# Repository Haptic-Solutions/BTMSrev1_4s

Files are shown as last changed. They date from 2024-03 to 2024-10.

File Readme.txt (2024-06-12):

Open Source Universal Battery Controller
Test battery is 4S Lithium Ion Pack
16.8V 2.6Ah rated. 38.48Wh Nominal
Please note that this device is a prototype and all features are still being extensively tested, some features aren't fully implement, and others are awaiting further polishing. Please excuse our mess as we continue to develop this system, it's documentation, and source/design repository.
Watch your step! The workshop is messy. ;)

	Though, this pack is worn out a bit as these are recycled cells. No worries though, as this BMS, Charger, and Power Management System will measure, and account for performance variations between batteries and chemistry types. Features include, but are not limited to:

    • BUCK-BOOST charge input to accommodate a wide range of battery configurations and supports charge voltage inputs from 5v-25v
    • USB-PD and USB2.0 charge to support a wide range of USB chargers up to 100watt.
    • AUX CHARGE PORT for solar applications
    • 2S, 3S, OR 4S support via jumper on the cell inputs
    • POWER SWITCH MODES ranging from push-and-hold, to automatic power on when charger power disconnected
    • FULL ACCESS to a wide range of settings such as cell max voltage and current
    • REDUNDANT SAFETY SYSTEMS not just in firmware but in hardware via over-voltage detection, shutdown, and disabling once any cell reaches 4.3v
    • ERROR REPORTING and TELEMETRY in a simple to access single letter command set via built-in USB serial or AUX UART header accessed by a terminal emulator
    • LCD SUPPORT via UART output that is configurable
    • HEATER CONTROL for cold environments with board and battery temperature sensors

Specs:
    • 25V 5A max charge input
    • 18V 10A max battery output, 2s-4s configurations, max 4.3v/cell
    • Dual UART with one dedicated to USB FTDI
    • dsPIC30F4011 micro-controller ~14mips
    • C codebase
    • 0.015mA deep-sleep (diode leakage, we aim to improve this)

Stay tuned for developments. We've got a lot of ground to cover before we release this into the wild! Our goal is to help other hobbyists be safer with batteries while getting their max performance in a very wide range of supported applications and cell chemistry types!
Copyright (2024) Haptic Solutions Inc.

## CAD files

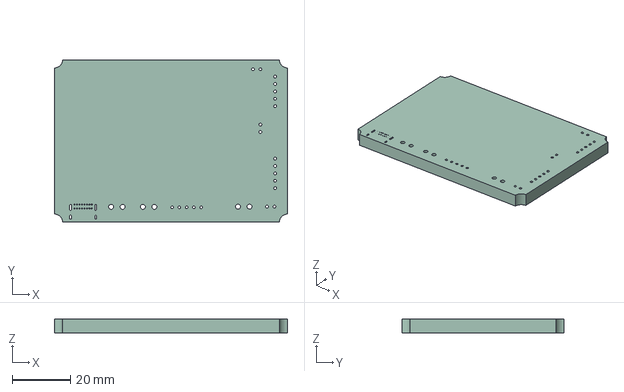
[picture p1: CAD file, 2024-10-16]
KICAD/BTMS.step
80.1 x 55.8 x 4.69 mm

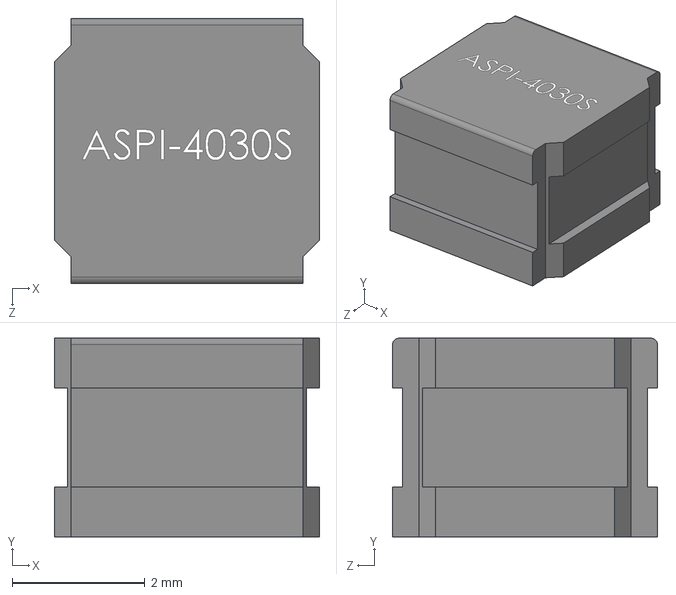
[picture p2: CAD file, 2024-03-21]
KICAD/inductorModel/ASPI-4030S-4R7M-T.step
4.00 x 3.00 x 4.00 mm

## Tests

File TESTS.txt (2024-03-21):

####################################
###  Functionality and safety tests to be performed. ###
####################################

******************************************************************************************************************************
## Functionality::

User interface:

Charging input(s) modes (USB, battery-to-battery, 5v-20v power supply, solar in with varying sunlight conditions):

Voltage output and power switch modes:

Charging efficiency > 85% through all modes:

Heater system:

******************************************************************************************************************************
## Safety systems::

Charge input over current detection and shutdown:

Power output over current detection and shutdown:

Cell low voltage shutdown and reporting:

Cell high voltage shutdown and reporting:

Over temperature shutdown for board and battery:

Under temperature charge slowdown/prevention:

******************************************************************************************************************************
## Compliance tests::

RF emissions within limits:

Battery Safety:

******************************************************************************************************************************
## Destructive tests::

Short circuit instant shutdown without blowing fuses:

Circuit board max current testing. Use blank boards and high-current source:

Overheat shutdown testing and abuse:

Battery HV disconnect fuse triggering at 4.3v per cell:

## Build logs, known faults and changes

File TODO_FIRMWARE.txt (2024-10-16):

####################################
##  Firmware features and bugs to be fixed and added ##
####################################

Fix: Charging routine not fully charging the battery and then maintaining the voltage. Testing fix.

Implement: MPPT for solar charging.

Implement: I2C communication to USB3.1 PD chip. Mostly done. Bug where re-plugging in the charger does not initiate USB3 charging. Testing fix for this. Seems to work alright after changing some things. Keep an eye on this.

Implement: Power button features. Done. Need to add a few features to this. Maybe an err ACK top bring back charge meter after a non-fatal error?

Implement: Better CLI interface such as more info available at request, and easier to understand variable names. Partly Done. Need to implement HUD config system.

Implement: Be able to change ALL settings from CLI. Mostly Done.

Fix: Fault light doesn't always turn on when an error is logged, especially when system shuts down, and doesn't always blink as it should.

Implement: New I2C hardware such as analog input and 4 bit digital IO expander need handlers.

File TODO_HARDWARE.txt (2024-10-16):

####################################
##  Hardware features and bugs to be fixed and added ##
####################################

Add: Small electrolytic decoupling capacitors to output of buck-boost converter. Might need some on input as well. Seems to trip USB-PD charges when average current isn't anywhere near it's set limit. Done some. Need to test more.

Upgrade: Current output rating is only 10 amps. Try to get it up to 15 amps. Not high priority. May not even bother with this version as it's small board size limits the current.

Fix: Lots of EMI coming from multiplexed LED drive circuit. <- Moved resistors as close to dsPIC as possible. Added resistor to multiplex selector. It's a little better. This might not be as bad as it seems.

Fix: USB and AUX charge inputs will output power to one or the other. This is NOT safe for either device that may be plugged in. <- New design uses a MOSFET network to switch USB input on/off. Need to test when new boards come in.

Fix: Capacitive loads cause inrush current that trips the over current protection circuit. A pre-charge circuit with resistors might work with some types of loads, but probably not when loads are both resistive and capacitive. <- Changed power source of
current sense IC's to an IO pin of the micro controller so that they can be reset when a known inrush current is about to be switched on. This did not work. Reverted back to powering current sense IC's from 3.3V analog supply.
Added RC network to turn MOSFETS on much slower. Need to test.

Fix: USB-PD chip senses wrong current with current schematic. Removed diode causing problems. Need better solution for powering PD chip from USB-C or Aux as it is also our 3.3V regulator to power the FTDI chip. Use separate regulator?

Fix: Sleep mode power draw still not low enough. Seems using these 40V Schottky diodes is part of the problem. Test show that removing D6 on REV1A(P) reduces sleep current draw from 0.15mA to just 0.05mA. Still not low enough, but better.
I only used these diodes because of their small size for how much current they can pass. Need to investigate further. Found that the buck-boost output diode is another source of leakage current. Removing the path from this circuit to the battery drops
the leakage current from battery down to 0.002mA which is within error of my cheap multi-meter. A 100mAh battery would last 5.7 years at this current while in sleep mode, and a 2.6Ah pack like the one I've been using to test would last 
~148 years in sleep mode.
Using newer design should improve this as the battery is completely disconnected when in deep-sleep mode.

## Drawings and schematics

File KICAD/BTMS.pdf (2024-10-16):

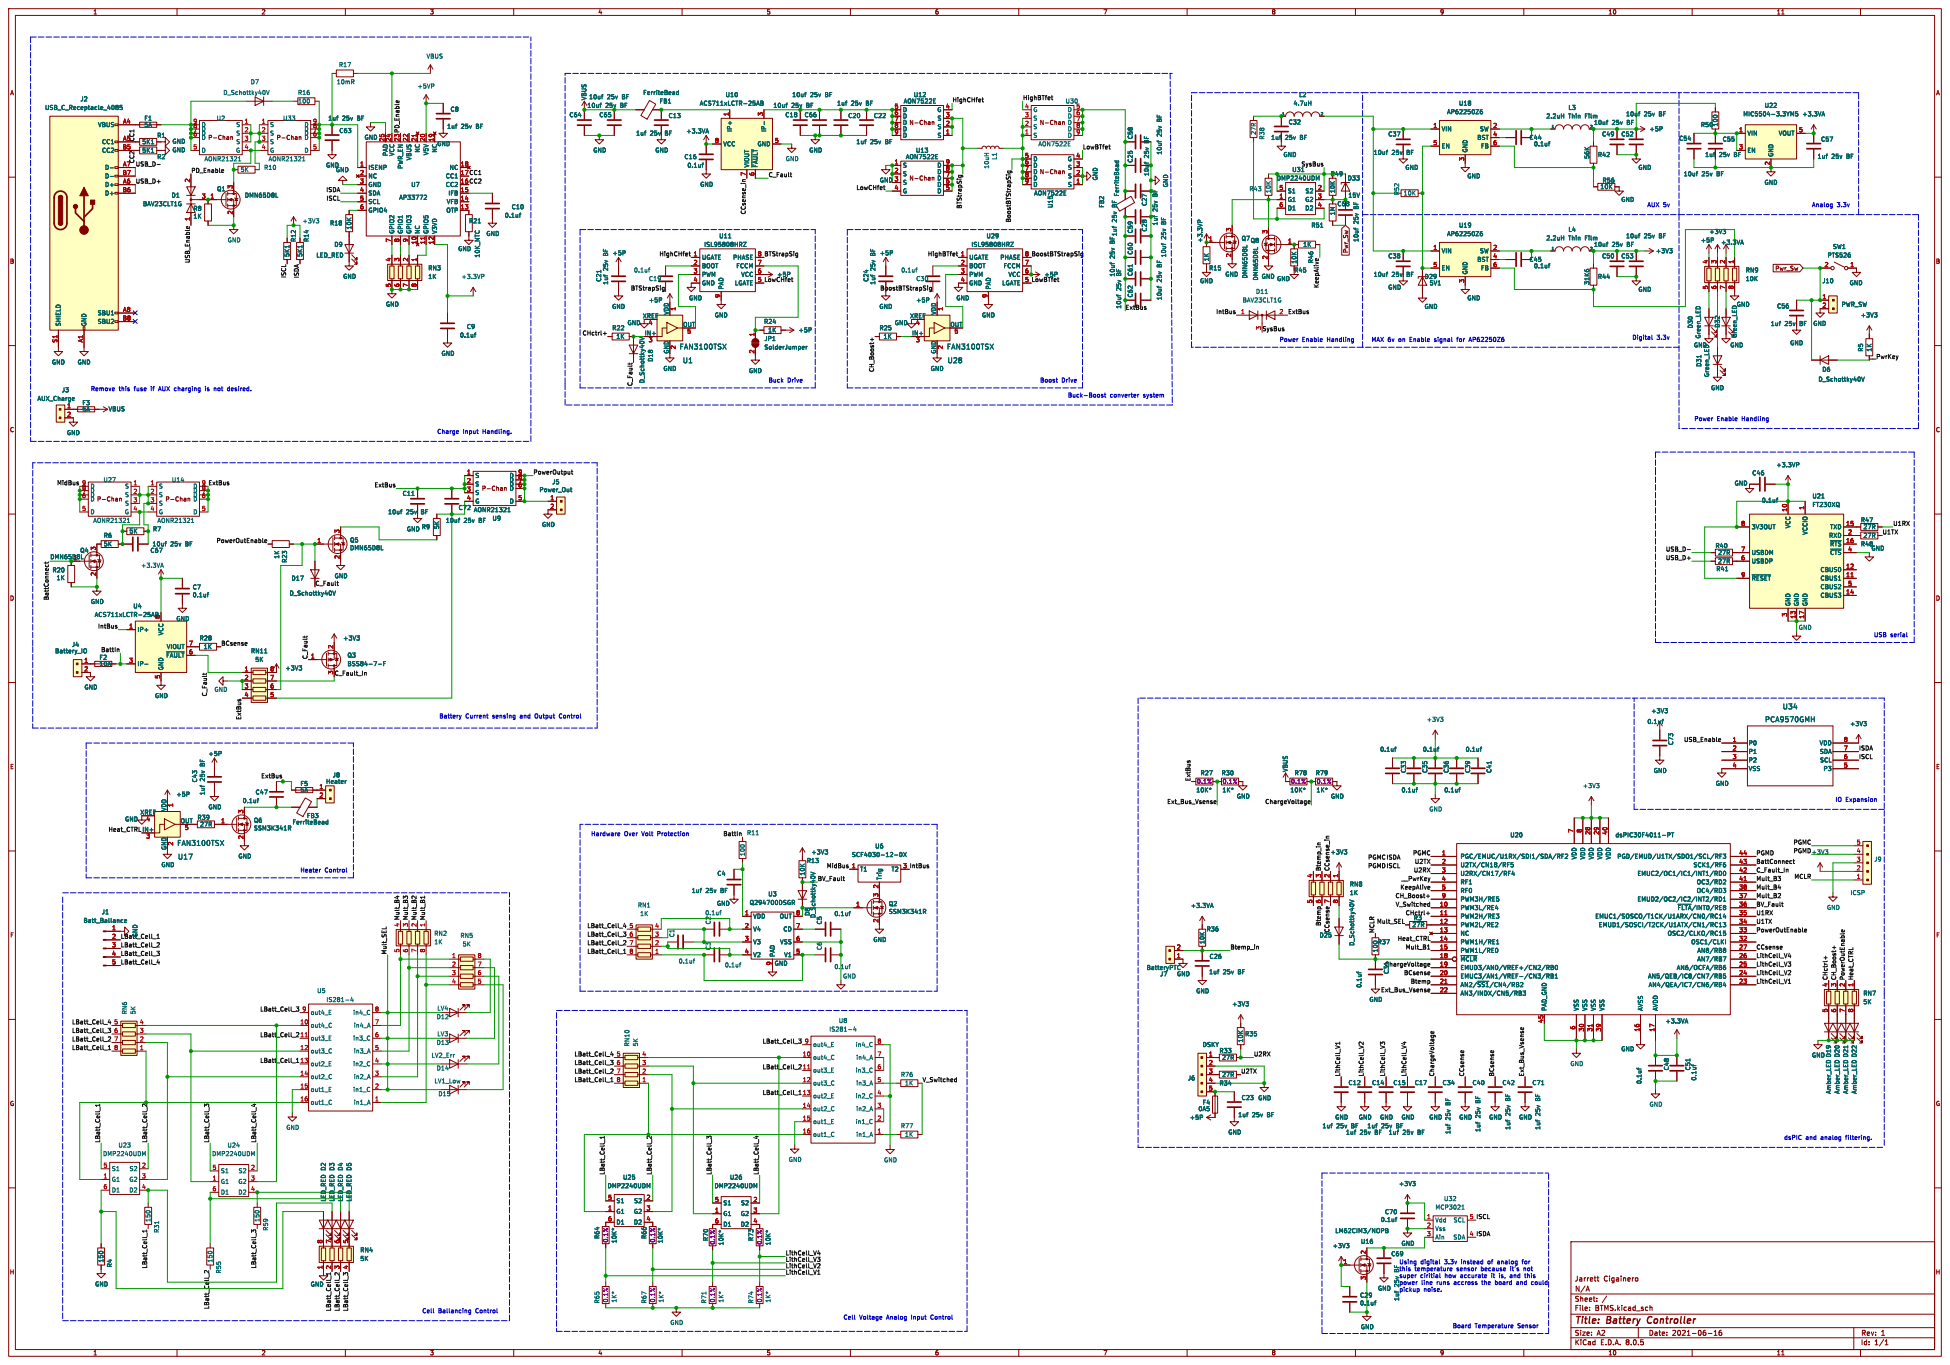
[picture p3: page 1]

7 VCC 8 U10 ACS711xLCTR-25AB UGATE 1 BOOT 2 PWM 3 GND 4

1 IP- 3 GND 5 ~{FAULT} 6 VIOUT

Power Enable Handling Boost Drive Charge Input Handling. R8

ISL95808HRZ UGATE 1 BOOT 2 PWM 3 GND 4

LGATE 5 VCC 6 FCCM 7 PHASE 8 PAD

MAX 6v on Enable signal for AP62250Z6

USB serial IO Expansion

Hardware Over Volt Protection Battery Current sensing and Output Control

Cell Voltage Analog Input Control

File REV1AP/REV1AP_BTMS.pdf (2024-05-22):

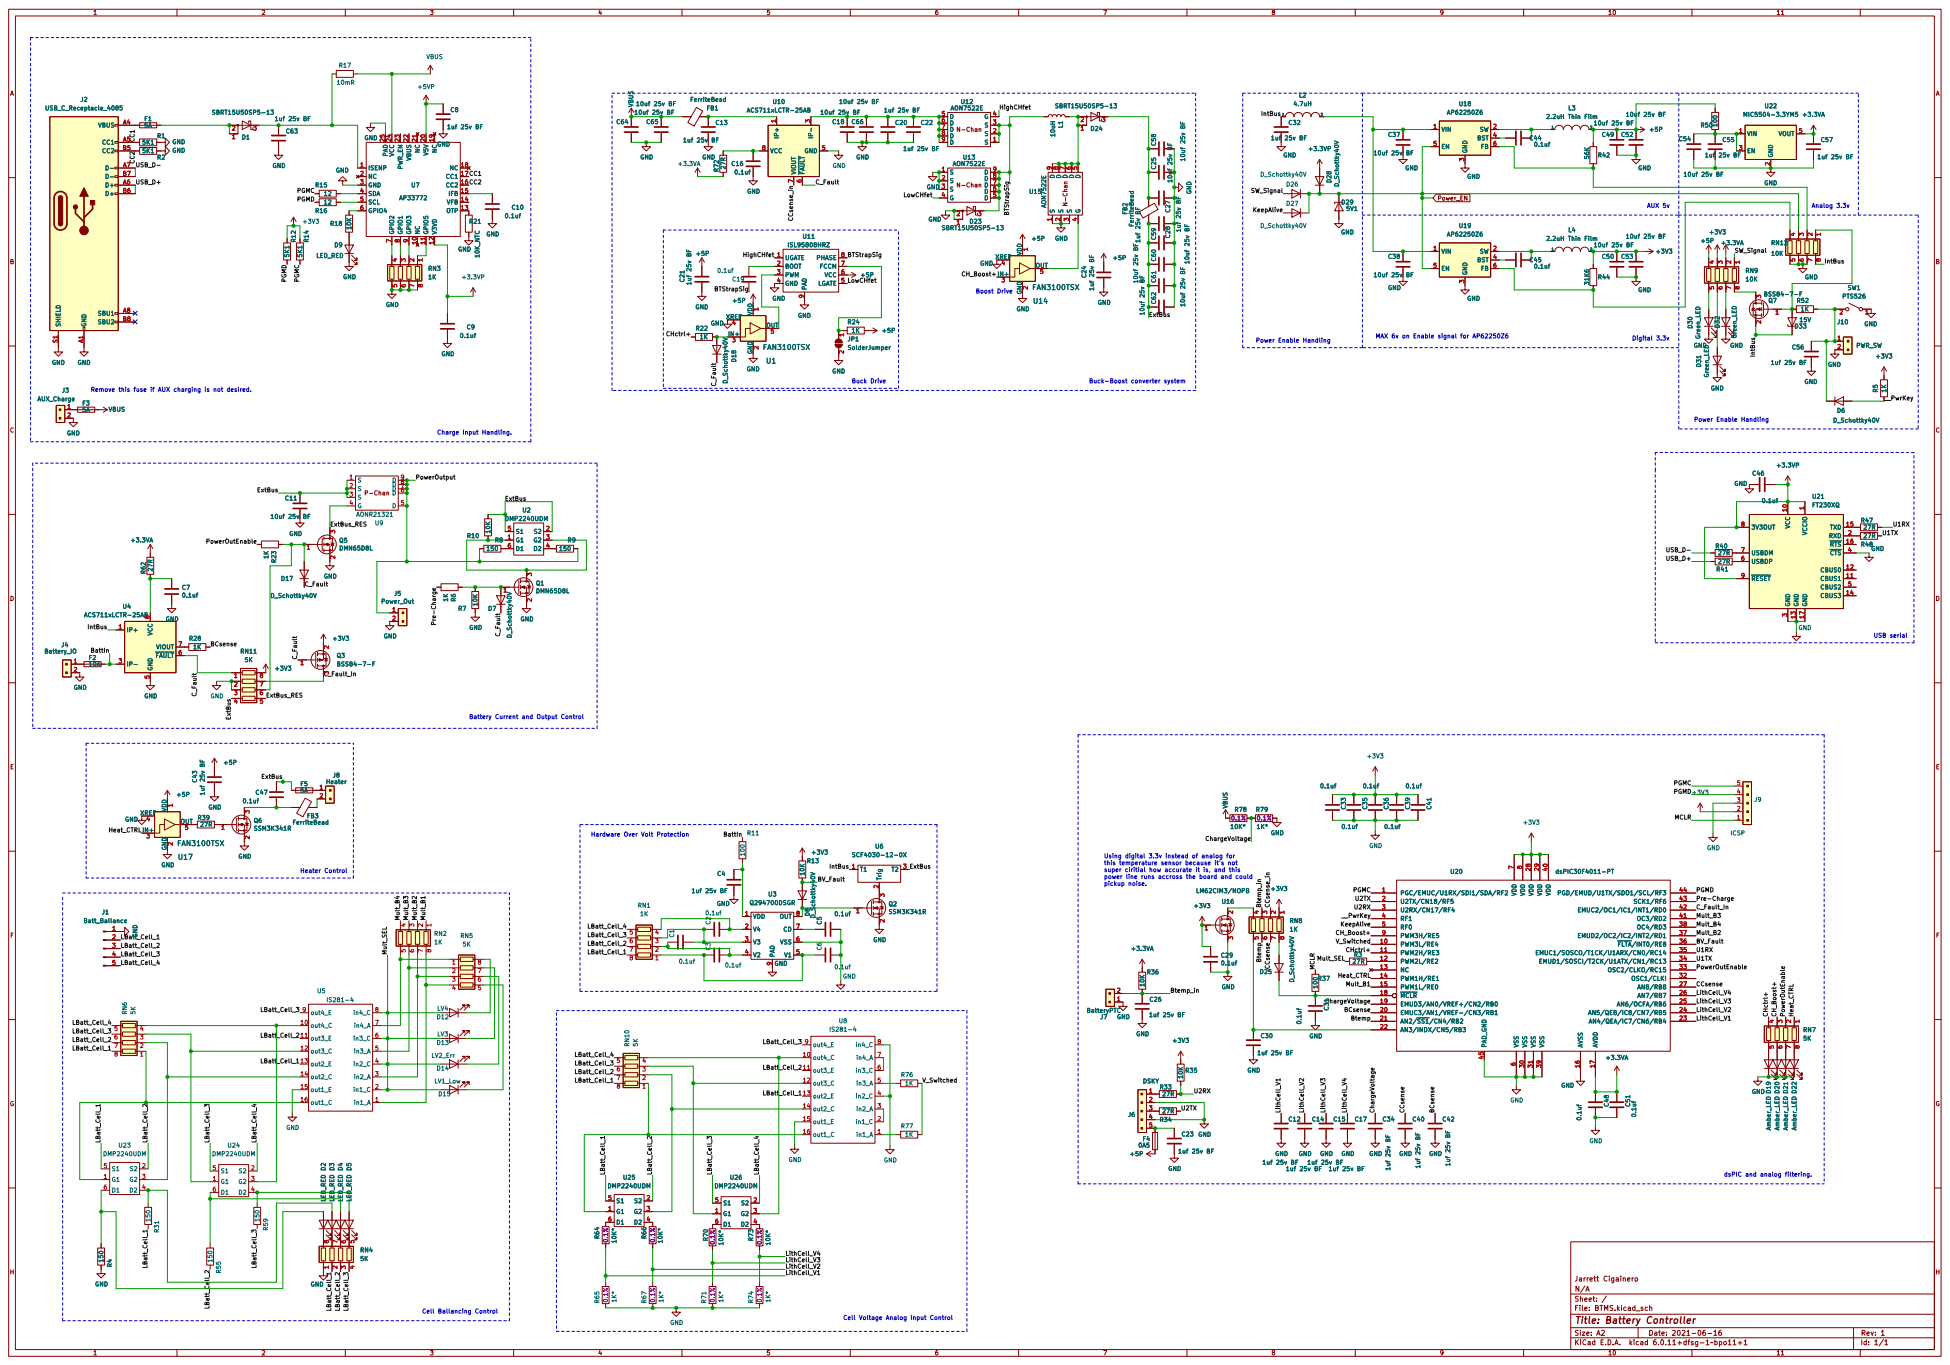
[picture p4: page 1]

1 IP- 3 GND 5 ~{FAULT} 6 VIOUT

9 +5P C24 1uf 25v BF L1 10uH GND C60 10uf 25v BF C62 10uf 25v BF GND FB2 FerriteBead C28 1uf 25v BF GND

Battery Current and Output Control

Hardware Over Volt Protection

dsPIC and analog filtering.

Jarrett Cigainero
Id: 1/1 Title: Battery Controller File: BTMS.kicad_sch Sheet: / N/A

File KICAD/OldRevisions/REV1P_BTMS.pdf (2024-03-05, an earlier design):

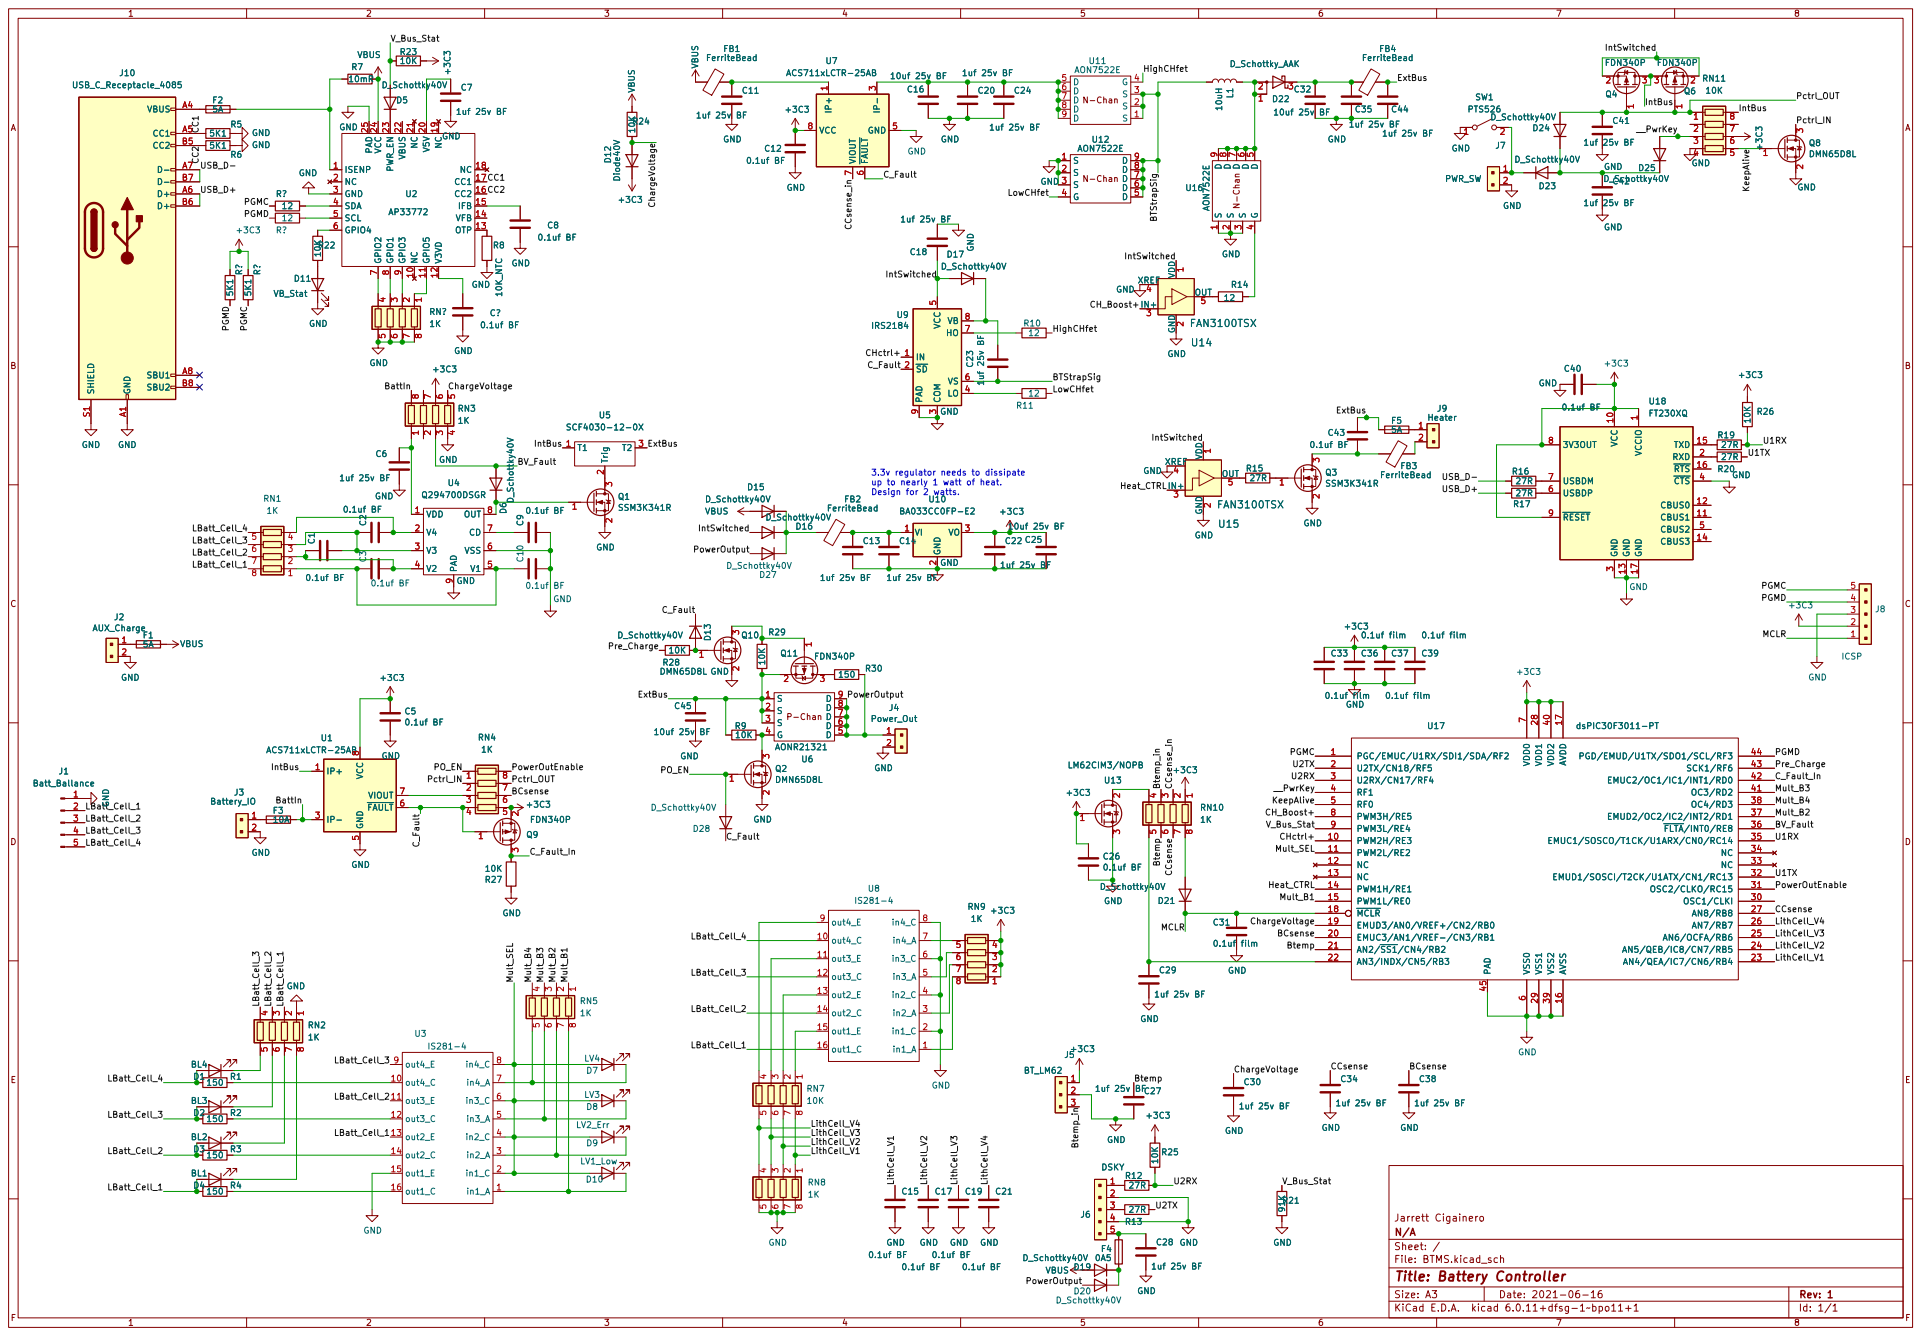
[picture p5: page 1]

1 IP- 3 GND 5 ~{FAULT} 6 VIOUT

Jarrett Cigainero
Id: 1/1 Title: Battery Controller File: BTMS.kicad_sch Sheet: / N/A

VBUS D20 D_Schottky40V GND GND GND

0.1uf BF GND GND GND

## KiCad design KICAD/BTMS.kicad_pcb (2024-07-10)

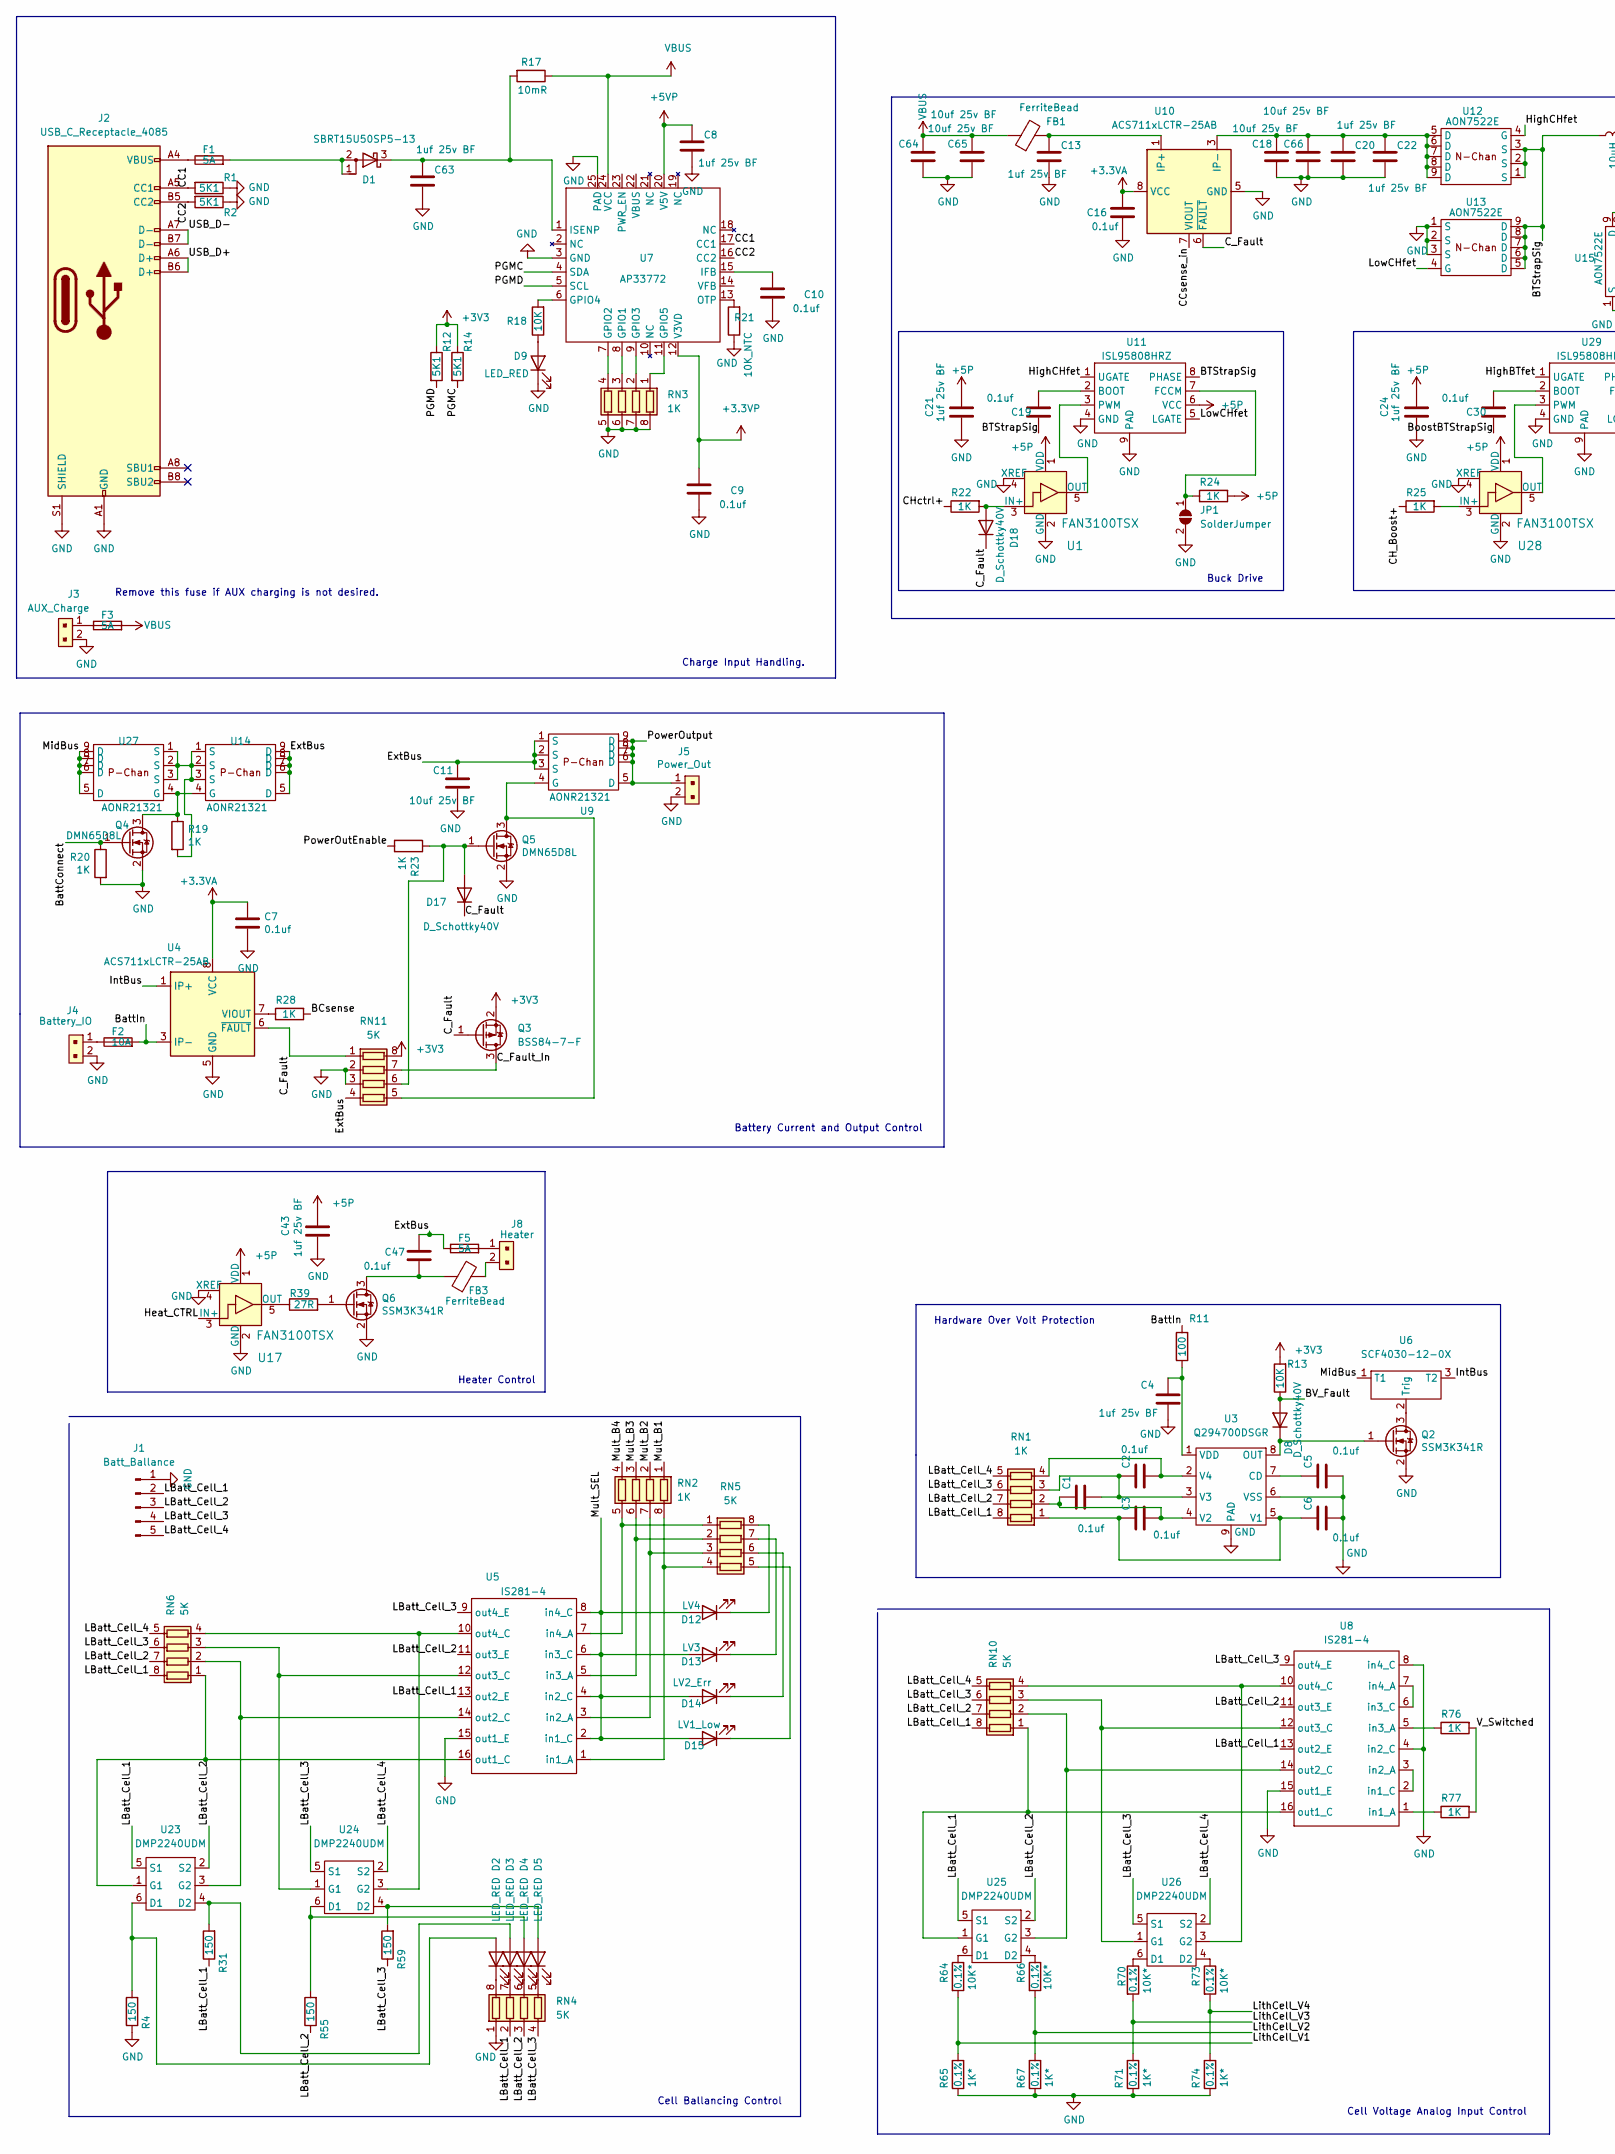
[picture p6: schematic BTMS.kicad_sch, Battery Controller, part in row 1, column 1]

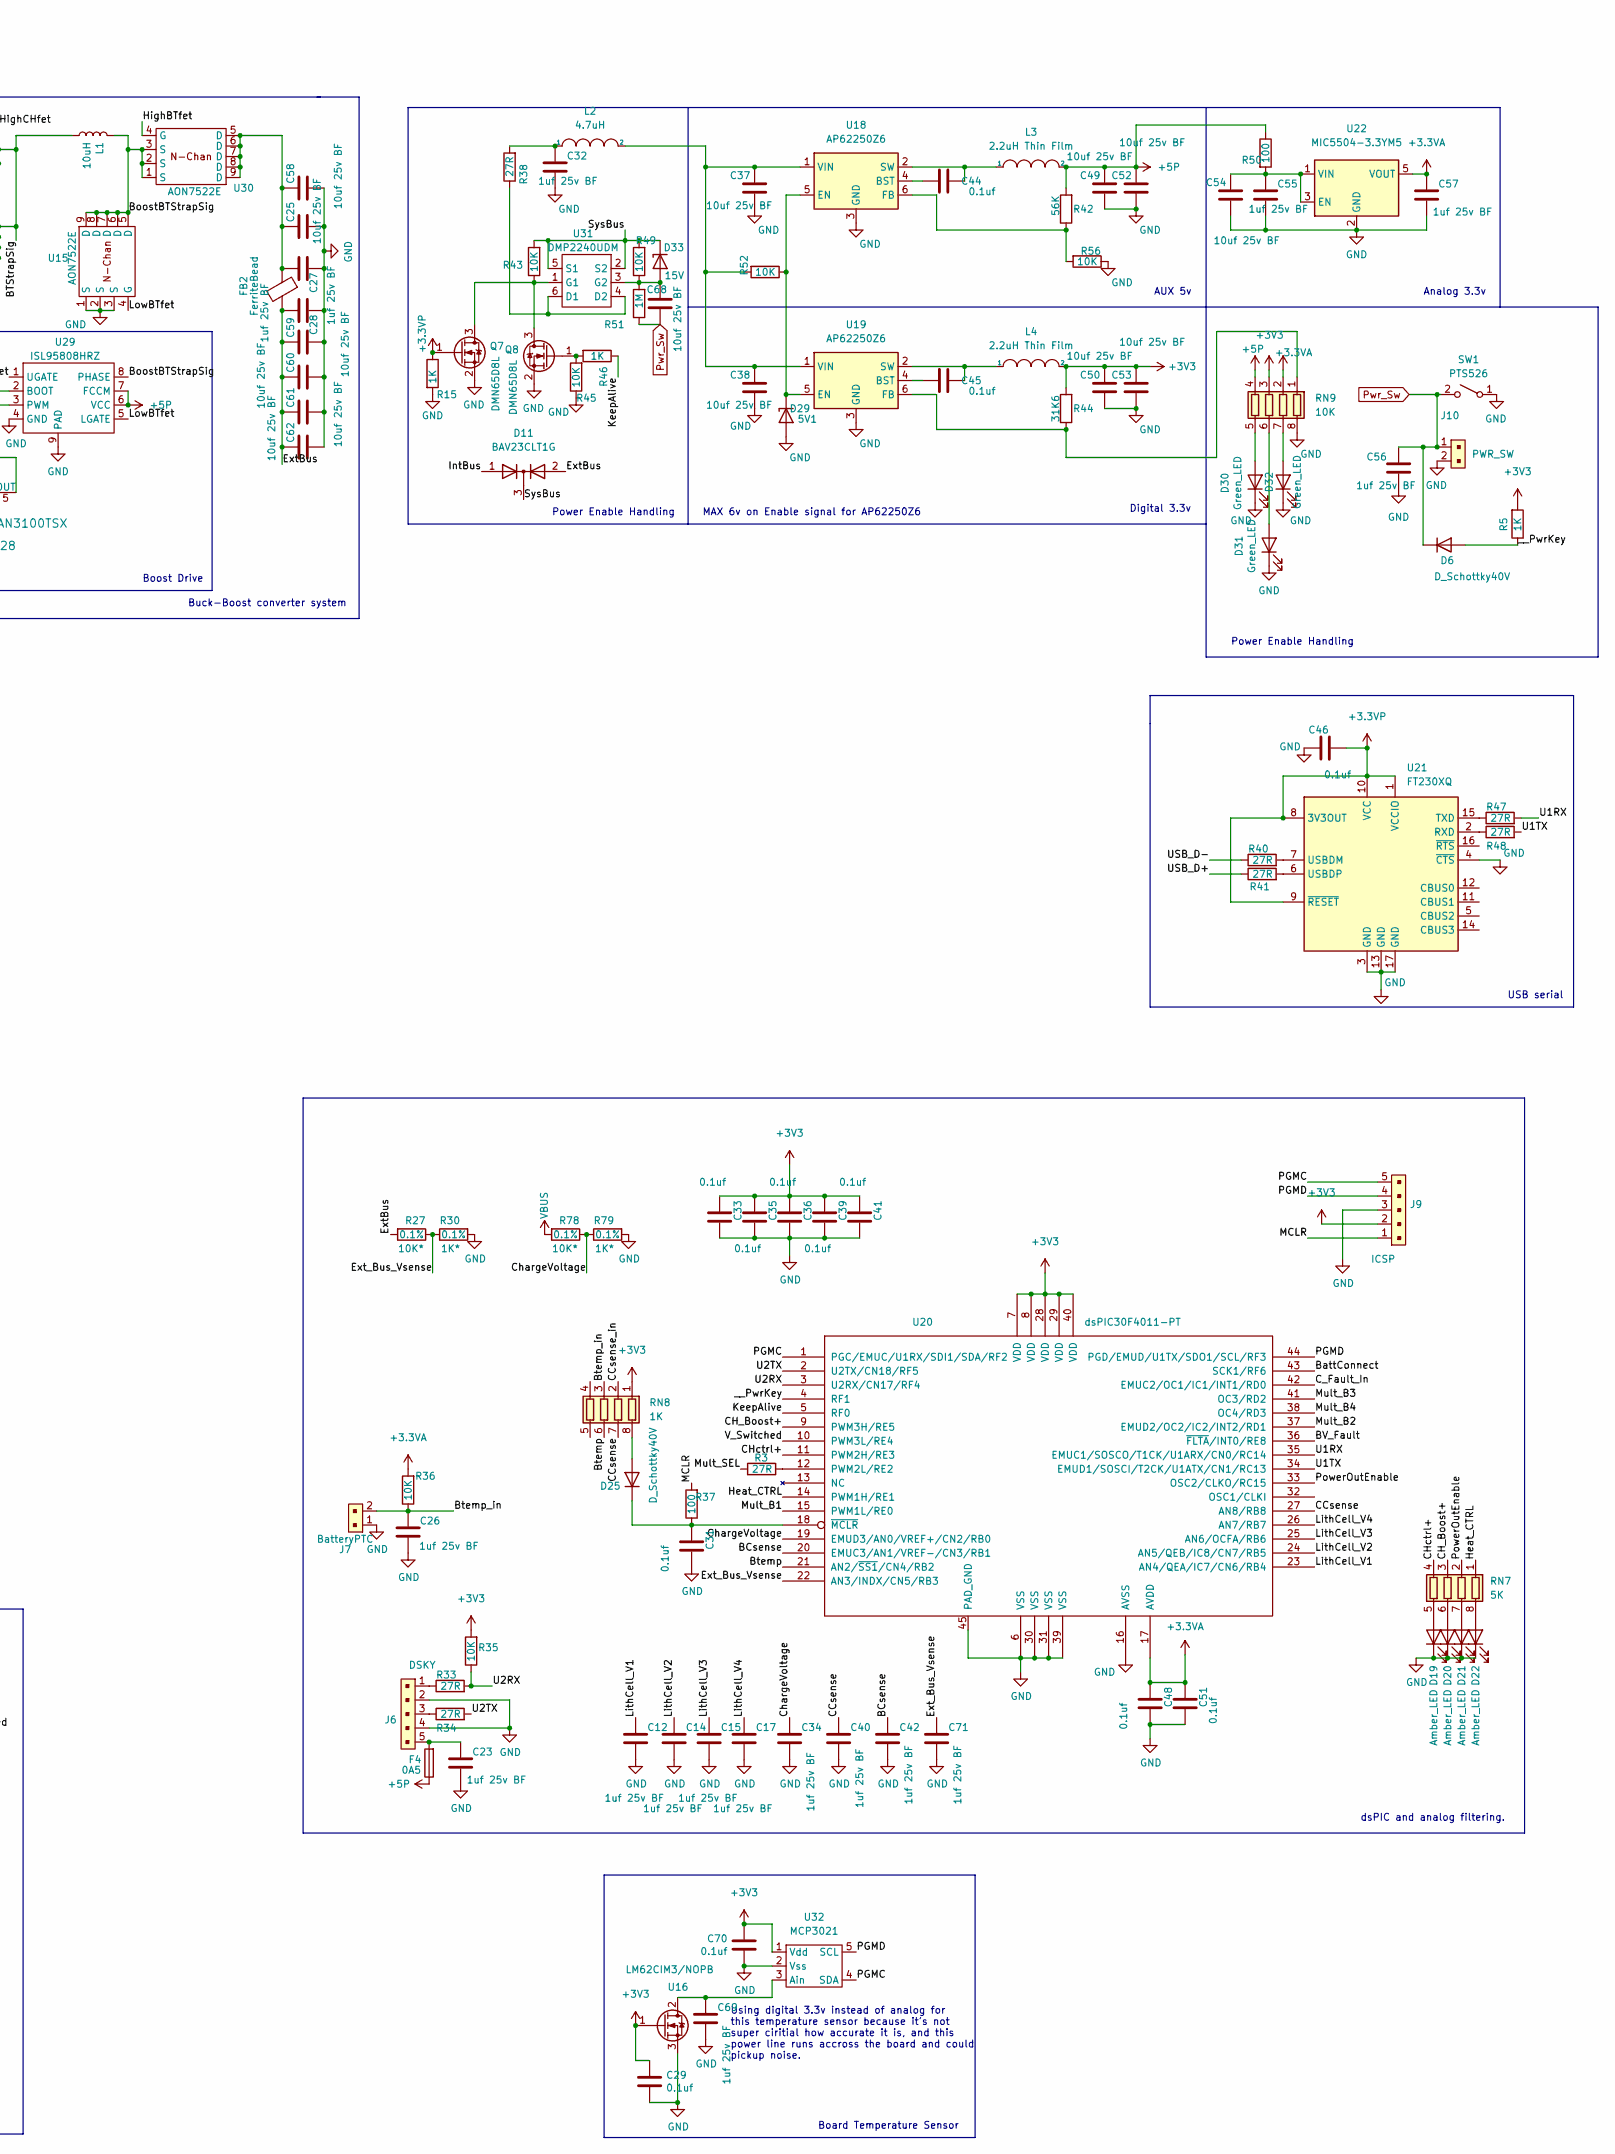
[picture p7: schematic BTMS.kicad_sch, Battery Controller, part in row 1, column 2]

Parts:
C1, C2, C3, C5, C6, C7, C9, C10, C16, C19, C29, C30, C31, C33, C35, C36, C39, C41, C44, C45, C46, C47, C48, C51, C70: 0.1uf; C_0402_1005Metric; Digi-Key_PN 1276-1043-1-ND
C4, C8, C12, C13, C14, C15, C17, C20, C21, C22, C23, C24, C26, C27, C28, C32, C34, C40, C42, C43, C55, C56, C57, C63, C69, C71: 1uf 25v BF; C_0402_1005Metric; Digi-Key_PN 445-175215-1-ND
C11, C18, C25, C37, C38, C49, C50, C52, C53, C54, C58, C59, C60, C61, C62, C64, C65, C66, C68: 10uf 25v BF; C_0805_2012Metric; Digi-Key_PN 490-GRJ21BR61E106KE01KCT-ND
D1: SBRT15U50SP5-13; TO-277B; Digi-Key_PN SBRT15U50SP5-13DICT-ND
D2, D3, D4, D5, D9: LED_RED; LED_0603_1608Metric; Digi-Key_PN 732-4978-1-ND
D6, D8, D17, D18, D25: D_Schottky40V; D_0603_1608Metric; Digi-Key_PN CCS15S40L3FCT-ND
D11: BAV23CLT1G; SOT-23; Digi-Key_PN BAV23CLT1GOSCT-ND
D12: LV4; LED_0603_1608Metric; Digi-Key_PN 732-4978-1-ND
D13: LV3; LED_0603_1608Metric; Digi-Key_PN 732-4978-1-ND
D14: LV2_Err; LED_0603_1608Metric; Digi-Key_PN 732-4978-1-ND
D15: LV1_Low; LED_0603_1608Metric; Digi-Key_PN 732-4978-1-ND
D19, D20, D21, D22: Amber_LED; LED_0603_1608Metric; Digi-Key_PN 732-150060AS75000CT-ND
D29: 5V1; D_SOD-123; Digi-Key_PN MMSZ5231B-FDICT-ND
D30, D31, D32: Green_LED; LED_0603_1608Metric; Digi-Key_PN 732-4971-1-ND
D33: 15V; D_SOD-123; Digi-Key_PN DDZ15-7DICT-ND
F1, F3, F5: 5A; Fuse_1206_3216Metric; Digi-Key_PN 507-1886-1-ND
F2: 10A; Fuse_1206_3216Metric; Digi-Key_PN 507-1942-1-ND
F4: 0A5; Fuse_0603_1608Metric_Pad1.05x0.95mm_HandSolder; Digi-Key_PN 507-1089-1-ND
FB1, FB2, FB3: FerriteBead; R_1206_3216Metric; Digi-Key_PN 490-13269-1-ND
J1: Batt_Ballance; JST_EH_S5B-EH_1x05_P2.50mm_Horizontal; Digi-Key_PN 455-4228-ND
J2: USB_C_Receptacle_4085; USB_C_Receptacle_GCT_USB4085; Digi-Key_PN 2073-USB4085-GF-ACT-ND
J3: AUX_Charge; JST_VH_B2PS-VH_1x02_P3.96mm_Horizontal; MPN 22-23-2021
J4: Battery_IO; JST_VH_B2PS-VH_1x02_P3.96mm_Horizontal; MPN 22-23-2021
J5: Power_Out; JST_VH_B2PS-VH_1x02_P3.96mm_Horizontal; MPN 22-23-2021
J6: DSKY; PinHeader_1x05_P2.54mm_Vertical; MPN B5B-XH-A(LF)(SN)
J7: BatteryPTC; PinHeader_1x02_P2.54mm_Vertical; MPN 22-23-2021
J8: Heater; PinHeader_1x02_P2.54mm_Vertical; MPN 22-23-2021
J9: ICSP; PinHeader_1x05_P2.54mm_Vertical; MPN B5B-XH-A(LF)(SN)
J10: PWR_SW; PinHeader_1x02_P2.54mm_Vertical; MPN 22-23-2021
JP1: SolderJumper; SolderJumper-2_P1.3mm_Open_TrianglePad1.0x1.5mm
L1: 10uH; L_12x12mm_H4.5mm; Digi-Key_PN SRP1265A-100MCT-ND
L2: 4.7uH; IND_ASPI-4030S-4R7M-T; Digi-Key_PN 535-12322-1-ND
L3, L4: 2.2uH Thin Film; L_0805_2012Metric_Pad1.15x1.40mm_HandSolder; Digi-Key_PN 1276-6901-1-ND
Q2, Q6: SSM3K341R; SOT-23; Digi-Key_PN SSM3K341RLFCT-ND
Q3: BSS84-7-F; SOT-23; Digi-Key_PN BSS84-FDICT-ND
Q4, Q5, Q7, Q8: DMN65D8L; SOT-23; Digi-Key_PN DMN65D8L-7DICT-ND
R1, R2, R12, R14: 5K1; R_0603_1608Metric; Digi-Key_PN 13-RC0603FR-135K1LCT-ND
R3, R33, R34, R38, R39, R40, R41, R47, R48: 27R; R_0603_1608Metric; Digi-Key_PN 13-RC0603FR-1327RLCT-ND
R4, R31, R55, R59: 150; R_0805_2012Metric_Pad1.20x1.40mm_HandSolder; Digi-Key_PN 2019-RK73B2ATTD151JCT-ND
R5, R15, R19, R20, R22, R23, R24, R25, R28, R46, R76, R77: 1K; R_0603_1608Metric; Digi-Key_PN 311-1.00KHRCT-ND
R11, R37, R50: 100; R_0603_1608Metric; Digi-Key_PN 311-100HRCT-ND
R13, R18, R35, R36, R43, R45, R49, R52, R56: 10K; R_0603_1608Metric; Digi-Key_PN CR0603-FX-1002ELFCT-ND
R17: 10mR; R_1206_3216Metric; Digi-Key_PN CSR1206FT10L0CT-ND
R21: 10K_NTC; R_0603_1608Metric; Digi-Key_PN RMCF0603FT91K0CT-ND
R27, R64, R66, R70, R73, R78: 10K*; R_0603_1608Metric; Digi-Key_PN YAG1236CT-ND
R30, R65, R67, R71, R74, R79: 1K*; R_0603_1608Metric; Digi-Key_PN YAG1237CT-ND
R42: 56K; R_0603_1608Metric; Digi-Key_PN 311-56KHRCT-ND
R44: 31K6; R_0603_1608Metric; Digi-Key_PN RMCF0603FT31K6CT-ND
R51: 1M; R_0603_1608Metric
RN1, RN2, RN3, RN8: 1K; R_Array_Convex_4x0612; Digi-Key_PN CAY16-1001F4LFCT-ND
RN4, RN5, RN6, RN7, RN10, RN11: 5K; R_Array_Convex_4x0612; Digi-Key_PN CAY16-4991F4LFCT-ND
RN9: 10K; R_Array_Convex_4x0612; Digi-Key_PN CAY16-1002F4LFCT-ND
SW1: PTS526; SW_SPST_SKQG_WithStem; Digi-Key_PN CKN12221-1-ND
U1, U17, U28: FAN3100TSX; SOT-23-5; MPN FAN3100TSX; Digi-Key_PN FAN3100TSXCT-ND
U3: Q294700DSGR; WDFN-8-1EP_2x2mm_P0.5mm_EP0.8x1.2mm; Digi-Key_PN 296-34984-1-ND
U4, U10: ACS711xLCTR-25AB; SOIC-8_3.9x4.9mm_P1.27mm; Digi-Key_PN 620-1371-1-ND
U5, U8: IS281-4; SOIC-16_4.55x10.3mm_P1.27mm; Digi-Key_PN IS281-4CT-ND
U6: SCF4030-12-0X; Digi-Key_PN 283-SCF4030-12-04CT-ND
U7: AP33772; WQFN-24-1EP_4x4mm_P0.5mm_EP2.6x2.6mm; Digi-Key_PN 31-AP33772DKZ-13CT-ND
U9, U14, U27: AONR21321; DFN-8-1EP_3x3mm_P0.65mm_EP1.7x2.05mm; Digi-Key_PN 785-1797-1-ND
U11, U29: ISL95808HRZ; DFN-8-1EP_2x2mm_P0.5mm_EP0.8x1.6mm; Digi-Key_PN 20-ISL95808HRZ-TCT-ND
U12, U13, U15, U30: AON7522E; DFN-8-1EP_3x3mm_P0.65mm_EP1.7x2.05mm; Digi-Key_PN 785-1505-1-ND
U16: LM62CIM3/NOPB; SOT-23; Digi-Key_PN LM62CIM3/NOPBCT-ND
U18, U19: AP62250Z6; SOT-563; Digi-Key_PN 31-AP62250Z6-7CT-ND
U20: dsPIC30F4011-PT; QFN-44-1EP_8x8mm_P0.65mm_EP6.45x6.45mm; Digi-Key_PN DSPIC30F401130IML-ND
U21: FT230XQ; QFN-16-1EP_4x4mm_P0.65mm_EP2.1x2.1mm; Digi-Key_PN 768-1130-1-ND
U22: MIC5504-3.3YM5; SOT-23-5; Digi-Key_PN 576-4764-1-ND
U23, U24, U25, U26, U31: DMP2240UDM; SOT-23-6; Digi-Key_PN DMP2240UDMDICT-ND
U32: MCP3021; SOT-23-5; Digi-Key_PN MCP3021A5T-E/OTCT-ND

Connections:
+3.3VA: C7.1, C16.1, C48.1, C51.1, C57.1, R36.2, RN9.2 (R2.1), U4.8 (VCC), U10.8 (VCC), U20.17 (AVDD), U22.5 (VOUT)
+3.3VP: C9.1, C46.2, Q7.1 (G), R15.1, U7.12 (V3VD), U21.1 (VCCIO), U21.8 (3V3OUT), U21.9 (~RESET), U21.10 (VCC)
+3V3: C29.1, C33.1, C35.1, C36.1, C39.1, C41.1, C50.1, C53.1, C70.1, J9.2, L4.2, Q3.2 (S), R5.2, R12.1, R13.2, R14.1, R35.2, R44.2, RN8.1 (R1.1), RN9.3 (R3.1), RN11.8 (R1.2), U16.1 (G), U20.7 (VDD), U20.8 (VDD), U20.28 (VDD), U20.29 (VDD), U20.40 (VDD), U32.1 (Vdd)
+5P: C21.1, C24.1, C43.1, C49.1, C52.1, F4.1, L3.2, R24.2, R42.2, R50.1, RN9.4 (R4.1), U1.1 (VDD), U11.6 (VCC), U17.1 (VDD), U28.1 (VDD), U29.6 (VCC), U29.7 (FCCM)
+5VP: C8.1, U7.20 (V5V)
/BCsense: C42.1, R28.2, U20.20 (EMUC3/AN1/VREF-/CN3/RB1)
/BTStrapSig: C19.2, L1.1, U11.8 (PHASE), U12.1 (S), U12.2 (S), U12.3 (S), U13.5 (D), U13.6 (D), U13.7 (D), U13.8 (D), U13.9 (D)
/BV_Fault: D8.2 (A), R13.1, U20.36 (~FLTA/INT0/RE8)
/BattConnect: Q4.1 (G), R20.1, U20.43 (SCK1/RF6)
/BattIn: F2.2, R11.2, U4.3 (IP-), U4.4 (IP-)
/BoostBTStrapSig: C30.2, L1.2, U15.5 (D), U15.6 (D), U15.7 (D), U15.8 (D), U15.9 (D), U29.8 (PHASE), U30.1 (S), U30.2 (S), U30.3 (S)
/Btemp: RN8.6 (R3.2), U20.21 (AN2/~SS1/CN4/RB2)
/Btemp_in: C26.1, J7.2, R36.1, RN8.3 (R3.1)
/CC1: J2.A5 (CC1), R1.2, U7.17 (CC1)
/CC2: J2.B5 (CC2), R2.2, U7.16 (CC2)
/CCsense: C40.1, RN8.7 (R2.2), U20.27 (AN8/RB8)
/CCsense_in: RN8.2 (R2.1), U10.7 (VIOUT)
/CH_Boost+: R25.1, RN7.3 (R3.1), U20.9 (PWM3H/RE5)
/CHctrl+: R22.1, RN7.4 (R4.1), U20.11 (PWM2H/RE3)
/C_Fault: D17.1 (K), D18.1 (K), Q3.1 (G), RN11.1 (R1.1), U4.6 (~FAULT), U10.6 (~FAULT)
/C_Fault_In: Q3.3 (D), RN11.7 (R2.2), U20.42 (EMUC2/OC1/IC1/INT1/RD0)
/ChargeVoltage: C34.1, R78.1, R79.1, U20.19 (EMUD3/AN0/VREF+/CN2/RB0)
/ExtBus: C11.1, C28.1, C47.1, C59.1, C60.1, C61.1, C62.1, D11.2 (A), F5.1, FB2.2, R27.2, RN11.4 (R4.1), U9.1 (S), U9.2 (S), U9.3 (S), U14.5 (D), U14.6 (D), U14.7 (D), U14.8 (D), U14.9 (D)
/Ext_Bus_Vsense: C71.1, R27.1, R30.1, U20.22 (AN3/INDX/CN5/RB3)
/Heat_CTRL: RN7.1 (R1.1), U17.3 (IN+), U20.14 (PWM1H/RE1)
/HighBTfet: U29.1 (UGATE), U30.4 (G)
/HighCHfet: U11.1 (UGATE), U12.4 (G)
/IntBus: D11.1 (A), U4.1 (IP+), U4.2 (IP+), U6.3 (T2)
/KeepAlive: R46.1, U20.5 (RF0)
/LBatt_Cell_1: J1.2, R31.1, RN1.8 (R1.2), RN4.2 (R2.1), RN6.8 (R1.2), RN10.8 (R1.2), U5.13 (out2_E), U8.13 (out2_E), U23.5 (S1), U25.5 (S1)
/LBatt_Cell_2: J1.3, R55.1, RN1.7 (R2.2), RN4.3 (R3.1), RN6.7 (R2.2), RN10.7 (R2.2), U5.11 (out3_E), U8.11 (out3_E), U23.2 (S2), U25.2 (S2)
/LBatt_Cell_3: J1.4, R59.1, RN1.6 (R3.2), RN4.4 (R4.1), RN6.6 (R3.2), RN10.6 (R3.2), U5.9 (out4_E), U8.9 (out4_E), U24.5 (S1), U26.5 (S1)
/LBatt_Cell_4: J1.5, RN1.5 (R4.2), RN6.5 (R4.2), RN10.5 (R4.2), U24.2 (S2), U26.2 (S2)
/LithCell_V1: C12.1, R64.2, R65.2, U20.23 (AN4/QEA/IC7/CN6/RB4)
/LithCell_V2: C14.1, R66.2, R67.2, U20.24 (AN5/QEB/IC8/CN7/RB5)
/LithCell_V3: C15.1, R70.2, R71.2, U20.25 (AN6/OCFA/RB6)
/LithCell_V4: C17.1, R73.2, R74.2, U20.26 (AN7/RB7)
/LowBTfet: U15.4 (G), U29.5 (LGATE)
/LowCHfet: U11.5 (LGATE), U13.4 (G)
/MCLR: J9.1, R37.2
/MidBus: U6.1 (T1), U27.5 (D), U27.6 (D), U27.7 (D), U27.8 (D), U27.9 (D)
/Mult_B1: RN2.1 (R1.1), U20.15 (PWM1L/RE0)
/Mult_B2: RN2.2 (R2.1), U20.37 (EMUD2/OC2/IC2/INT2/RD1)
/Mult_B3: RN2.3 (R3.1), U20.41 (OC3/RD2)
/Mult_B4: RN2.4 (R4.1), U20.38 (OC4/RD3)
/Mult_SEL: D12.2 (A), D13.2 (A), D14.2 (A), D15.2 (A), R3.1, U5.2 (in1_C), U5.4 (in2_C), U5.6 (in3_C), U5.8 (in4_C)
/PGMC: J9.5, R14.2, U7.4 (SDA), U20.1 (PGC/EMUC/U1RX/SDI1/SDA/RF2), U32.4 (SDA)
/PGMD: J9.4, R12.2, U7.5 (SCL), U20.44 (PGD/EMUD/U1TX/SDO1/SCL/RF3), U32.5 (SCL)
/PowerOutEnable: R23.2, RN7.2 (R2.1), U20.33 (OSC2/CLKO/RC15)
/PowerOutput: J5.1, U9.5 (D), U9.6 (D), U9.7 (D), U9.8 (D), U9.9 (D)
/SysBus: D11.3 (K), D33.1 (K), R43.2, R49.2, U31.2 (S2), U31.5 (S1)
/U1RX: R47.2, U20.35 (EMUC1/SOSCO/T1CK/U1ARX/CN0/RC14)
/U1TX: R48.2, U20.34 (EMUD1/SOSCI/T2CK/U1ATX/CN1/RC13)
/U2RX: R33.2, R35.1, U20.3 (U2RX/CN17/RF4)
/U2TX: R34.2, U20.2 (U2TX/CN18/RF5)
/USB_D+: J2.A6 (D+), J2.B6 (D+), R41.1
/USB_D-: J2.A7 (D-), J2.B7 (D-), R40.1
/V_Switched: R76.2, R77.2, U20.10 (PWM3L/RE4)
/__PwrKey: D6.2 (A), R5.1, U20.4 (RF1)
GND: C4.2, C5.2, C6.2, C7.2, C8.2, C9.2, C10.2, C11.2, C12.2, C13.2, C14.2, C15.2, C16.2, C17.2, C18.2, C20.2, C21.2, C22.2, C23.2, C24.2, C25.2, C26.2, C27.2, C28.2, C29.2, C31.2, C32.2, C33.2, C34.2, C35.2, C36.2, C37.2, C38.2, C39.2, C40.2, C41.2, C42.2, C43.2, C46.1, C48.2, C49.2, C50.2, C51.2, C52.2, C53.2, C54.2, C55.2, C56.2, C57.2, C58.2, C59.2, C60.2, C61.2, C62.2, C63.2, C64.2, C65.2, C66.2, C69.2, C70.2, C71.2, D9.1 (K), D19.1 (K), D20.1 (K), D21.1 (K), D22.1 (K), D29.2 (A), D30.1 (K), D31.1 (K), D32.1 (K), J1.1, J2.A1 (GND), J2.A12 (GND), J2.B1 (GND), J2.B12 (GND), J2.S1 (SHIELD), J3.2, J4.2, J5.2, J6.2, J6.4, J7.1, J9.3, J10.2, JP1.2 (B), Q2.2 (S), Q4.2 (S), Q5.2 (S), Q6.2 (S), Q7.2 (S), Q8.2 (S), R1.1, R2.1, R4.1, R15.2, R20.2, R21.1, R30.2, R45.1, R56.1, R65.1, R67.1, R71.1, R74.1, R79.2, RN3.5 (R4.2), RN3.6 (R3.2), RN3.7 (R2.2), RN3.8 (R1.2), RN4.1 (R1.1), RN9.8 (R1.2), RN11.2 (R2.1), RN11.3 (R3.1), SW1.1 (A), U1.2 (GND), U1.4 (XREF), U3.6 (VSS), U3.9 (PAD), U4.5 (GND), U5.15 (out1_E), U7.3 (GND), U7.25 (PAD), U8.4 (in2_C), U8.8 (in4_C), U8.15 (out1_E), U10.5 (GND), U11.4 (GND), U11.9 (PAD), U13.1 (S), U13.2 (S), U13.3 (S), U15.1 (S), U15.2 (S), U15.3 (S), U16.3 (S), U17.2 (GND), U17.4 (XREF), U18.3 (GND), U19.3 (GND), U20.6 (VSS), U20.16 (AVSS), U20.30 (VSS), U20.31 (VSS), U20.39 (VSS), U20.45 (PAD_GND), U21.3 (GND), U21.4 (~CTS), U21.13 (GND), U21.17 (GND), U22.2 (GND), U28.2 (GND), U28.4 (XREF), U29.4 (GND), U29.9 (PAD), U32.2 (Vss)
unnamed: C1.1, C3.2, RN1.2 (R2.1), U3.4 (V2)
unnamed: C1.2, C2.1, RN1.3 (R3.1), U3.3 (V3)
unnamed: C2.2, RN1.4 (R4.1), U3.2 (V4)
unnamed: C3.1, C6.1, RN1.1 (R1.1), U3.5 (V1)
unnamed: C4.1, R11.1, U3.1 (VDD)
unnamed: C5.1, U3.7 (CD)
unnamed: C10.1, U7.15 (IFB)
unnamed: C13.1, FB1.2, U10.1 (IP+), U10.2 (IP+)
unnamed: C18.1, C20.1, C22.1, C66.1, U10.3 (IP-), U10.4 (IP-), U12.5 (D), U12.6 (D), U12.7 (D), U12.8 (D), U12.9 (D)
unnamed: C19.1, U11.2 (BOOT)
unnamed: C23.1, F4.2, J6.5
unnamed: C25.1, C27.1, C58.1, FB2.1, U30.5 (D), U30.6 (D), U30.7 (D), U30.8 (D), U30.9 (D)
unnamed: C30.1, U29.2 (BOOT)
unnamed: C31.1, D25.1 (K), R37.1, U20.18 (~MCLR)
unnamed: C32.1, L2.1, R38.2
unnamed: C37.1, C38.1, L2.2, R52.2, U18.1 (VIN), U19.1 (VIN)
unnamed: C44.1, U18.4 (BST)
unnamed: C44.2, L3.1, U18.2 (SW)
unnamed: C45.1, U19.4 (BST)
unnamed: C45.2, L4.1, U19.2 (SW)
unnamed: C47.2, FB3.1, Q6.3 (D)
unnamed: C54.1, C55.1, R50.2, U22.1 (VIN), U22.3 (EN)
unnamed: C63.1, D1.3 (K), R17.2, U7.1 (ISENP)
unnamed: C68.1, D33.2 (A), R49.1, R51.2, U31.3 (G2)
unnamed: C69.1, U16.2 (D), U32.3 (Ain)
unnamed: D1.1 (A), D1.2 (A), F1.2
unnamed: D2.1 (K), RN4.8 (R1.2)
unnamed: D2.2 (A), R4.2, U23.6 (D1)
unnamed: D3.1 (K), RN4.7 (R2.2)
unnamed: D3.2 (A), R31.2, U23.4 (D2)
unnamed: D4.1 (K), RN4.6 (R3.2)
unnamed: D4.2 (A), R55.2, U24.6 (D1)
unnamed: D5.1 (K), RN4.5 (R4.2)
unnamed: D5.2 (A), R59.2, U24.4 (D2)
unnamed: D8.1 (K), Q2.1 (G), U3.8 (OUT)
unnamed: D9.2 (A), R18.1
unnamed: D12.1 (K), RN5.8 (R1.2)
unnamed: D13.1 (K), RN5.7 (R2.2)
unnamed: D14.1 (K), RN5.6 (R3.2)
unnamed: D15.1 (K), RN5.5 (R4.2)
unnamed: D17.2 (A), Q5.1 (G), R23.1, RN11.6 (R3.2)
unnamed: D18.2 (A), R22.2, U1.3 (IN+)
unnamed: D19.2 (A), RN7.5 (R4.2)
unnamed: D20.2 (A), RN7.6 (R3.2)
unnamed: D21.2 (A), RN7.7 (R2.2)
unnamed: D22.2 (A), RN7.8 (R1.2)
unnamed: D25.2 (A), RN8.8 (R1.2)
unnamed: D29.1 (K), R52.1, U18.5 (EN), U19.5 (EN)
unnamed: D30.2 (A), RN9.5 (R4.2)
unnamed: D31.2 (A), RN9.6 (R3.2)
unnamed: D32.2 (A), RN9.7 (R2.2)
unnamed: F1.1, J2.A4 (VBUS), J2.A9 (VBUS), J2.B4 (VBUS), J2.B9 (VBUS)
unnamed: F2.1, J4.1
unnamed: F3.1, J3.1
unnamed: F5.2, J8.1
unnamed: FB3.2, J8.2
unnamed: J6.1, R33.1
unnamed: J6.3, R34.1
unnamed: JP1.1 (A), R24.1, U11.7 (FCCM)
unnamed: Q2.3 (D), U6.2 (Trig)
unnamed: Q4.3 (D), R19.1, U14.4 (G), U27.4 (G)
unnamed: Q5.3 (D), RN11.5 (R4.2), U9.4 (G)
unnamed: Q6.1 (G), R39.2
unnamed: Q7.3 (D), Q8.3 (D), R43.1, U31.1 (G1)
unnamed: Q8.1 (G), R45.2, R46.2
unnamed: R3.2, U20.12 (PWM2L/RE2)
unnamed: R18.2, U7.6 (GPIO4)
unnamed: R19.2, U14.1 (S), U14.2 (S), U14.3 (S), U27.1 (S), U27.2 (S), U27.3 (S)
unnamed: R21.2, U7.13 (OTP)
unnamed: R25.2, U28.3 (IN+)
unnamed: R28.1, U4.7 (VIOUT)
unnamed: R38.1, U31.4 (D2), U31.6 (D1)
unnamed: R39.1, U17.5 (OUT)
unnamed: R40.2, U21.7 (USBDM)
unnamed: R41.2, U21.6 (USBDP)
unnamed: R42.1, R56.2, U18.6 (FB)
unnamed: R44.1, RN9.1 (R1.1), U19.6 (FB)
unnamed: R47.1, U21.15 (TXD)
unnamed: R48.1, U21.2 (RXD)
unnamed: R64.1, U25.6 (D1)
unnamed: R66.1, U25.4 (D2)
unnamed: R70.1, U26.6 (D1)
unnamed: R73.1, U26.4 (D2)
unnamed: R76.1, U8.5 (in3_A)
unnamed: R77.1, U8.1 (in1_A)
unnamed: RN2.5 (R4.2), RN5.1 (R1.1), U5.7 (in4_A)
unnamed: RN2.6 (R3.2), RN5.2 (R2.1), U5.5 (in3_A)
unnamed: RN2.7 (R2.2), RN5.3 (R3.1), U5.3 (in2_A)
unnamed: RN2.8 (R1.2), RN5.4 (R4.1), U5.1 (in1_A)
unnamed: RN3.1 (R1.1), U7.11 (GPIO5)
unnamed: RN3.2 (R2.1), U7.9 (GPIO3)
unnamed: RN3.3 (R3.1), U7.8 (GPIO1)
unnamed: RN3.4 (R4.1), U7.7 (GPIO2)
unnamed: RN6.1 (R1.1), U5.16 (out1_C), U23.1 (G1)
unnamed: RN6.2 (R2.1), U5.14 (out2_C), U23.3 (G2)
unnamed: RN6.3 (R3.1), U5.12 (out3_C), U24.1 (G1)
unnamed: RN6.4 (R4.1), U5.10 (out4_C), U24.3 (G2)
unnamed: RN10.1 (R1.1), U8.16 (out1_C), U25.1 (G1)
unnamed: RN10.2 (R2.1), U8.14 (out2_C), U25.3 (G2)
unnamed: RN10.3 (R3.1), U8.12 (out3_C), U26.1 (G1)
unnamed: RN10.4 (R4.1), U8.10 (out4_C), U26.3 (G2)
unnamed: U1.5 (OUT), U11.3 (PWM)
unnamed: U8.2 (in1_C), U8.3 (in2_A)
unnamed: U8.6 (in3_C), U8.7 (in4_A)
unnamed: U28.5 (OUT), U29.3 (PWM)
Pwr_Sw: C56.1, C68.2, D6.1 (K), J10.1, R51.1, SW1.2 (B)
VBUS: C64.1, C65.1, F3.2, FB1.1, R17.1, R78.2, U7.24 (VCC)

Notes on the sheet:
USB serial
Power Enable Handling
Remove this fuse if AUX charging is not desired.
AUX 5v
Cell Voltage Analog Input Control
Buck-Boost converter system
Buck Drive
Board Temperature Sensor
Battery Current and Output Control
Heater Control
dsPIC and analog filtering.
Boost Drive
Cell Ballancing Control
MAX 6v on Enable signal for AP62250Z6
Hardware Over Volt Protection
Digital 3.3v
Analog 3.3v
Using digital 3.3v instead of analog for this temperature sensor because it's not super ciritial how accurate it is, and this power line runs accross the board and could pickup noise.
Charge Input Handling.

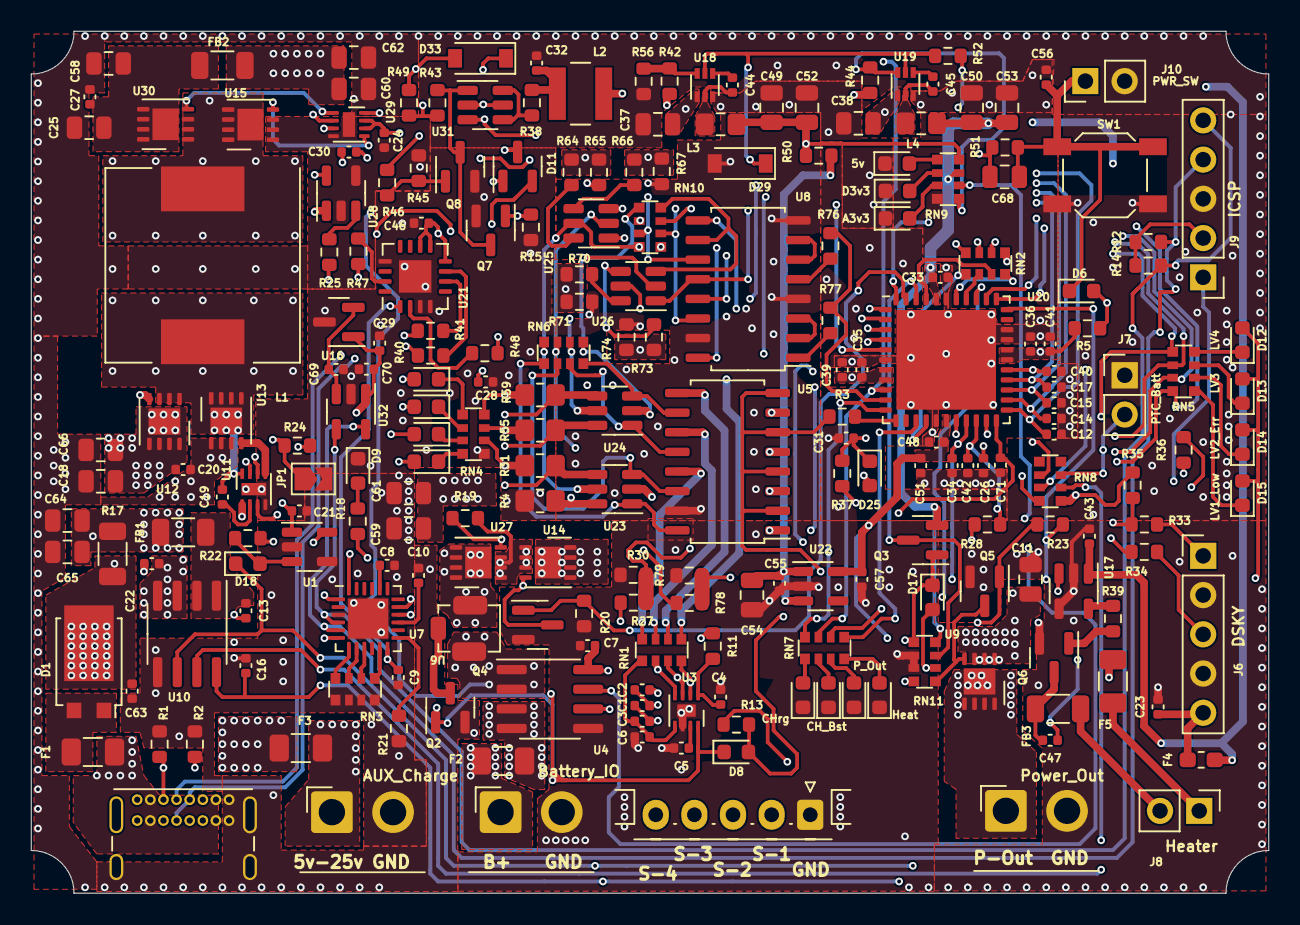
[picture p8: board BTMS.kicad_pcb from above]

Board: 4 copper layers, 80.1 x 55.8 mm, 226 parts (0 on the bottom side), 167 nets.

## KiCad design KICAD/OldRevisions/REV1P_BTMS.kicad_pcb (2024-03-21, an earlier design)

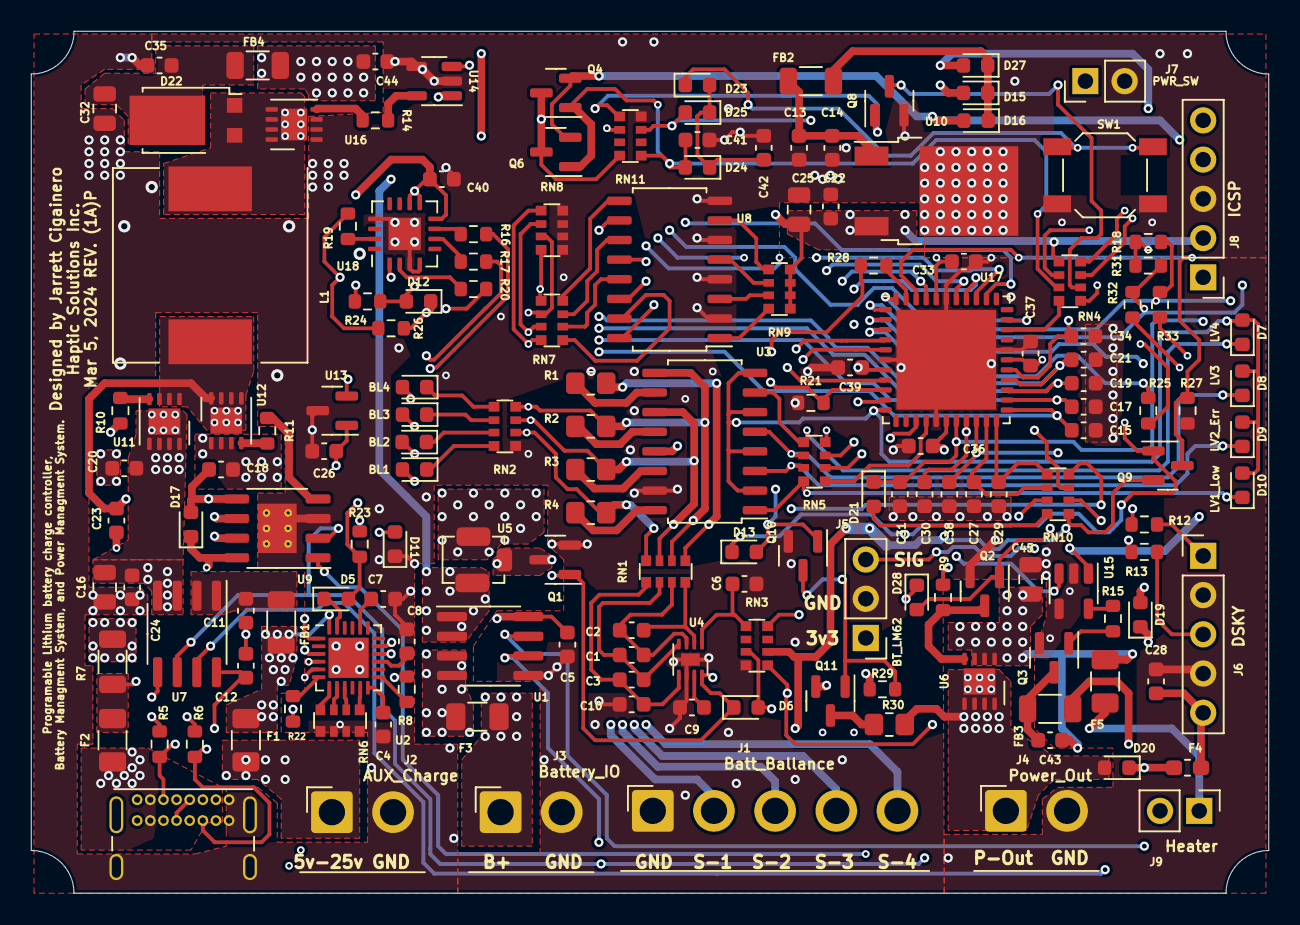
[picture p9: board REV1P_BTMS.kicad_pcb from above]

Board: 4 copper layers, 80.1 x 55.8 mm, 162 parts (0 on the bottom side), 134 nets.

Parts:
C1, C2, C3, C4, C5, C8, C9, C10, C12, C15, C17, C19, C21, C26, C40, C43: 0.1uf BF; C_0603_1608Metric
C6, C7, C11, C13, C14, C18, C20, C22, C23, C24, C27, C28, C29, C30, C34, C35, C38, C41, C42, C44: 1uf 25v BF; C_0603_1608Metric
C16, C25, C32, C45: 10uf 25v BF; C_0805_2012Metric
C31, C33, C36, C37, C39: 0.1uf film; C_0603_1608Metric
D1: BL4; LED_0603_1608Metric
D2: BL3; LED_0603_1608Metric
D3: BL2; LED_0603_1608Metric
D4: BL1; LED_0603_1608Metric
D5, D6, D13, D15, D16, D17, D19, D20, D21, D23, D24, D25, D27, D28: D_Schottky40V; D_0603_1608Metric
D7: LV4; LED_0603_1608Metric
D8: LV3; LED_0603_1608Metric
D9: LV2_Err; LED_0603_1608Metric
D10: LV1_Low; LED_0603_1608Metric
D11: VB_Stat; LED_0603_1608Metric
D12: Diode40V; D_0603_1608Metric
D22: D_Schottky_AAK; TO-277B
F1, F2, F5: 5A; Fuse_1206_3216Metric
F3: 10A; Fuse_1206_3216Metric
F4: 0A5; Fuse_0603_1608Metric_Pad1.05x0.95mm_HandSolder
FB1, FB2, FB3, FB4: FerriteBead; R_1206_3216Metric
J1: Batt_Ballance; JST_VH_B5PS-VH_1x05_P3.96mm_Horizontal
J2: AUX_Charge; JST_VH_B2PS-VH_1x02_P3.96mm_Horizontal
J3: Battery_IO; JST_VH_B2PS-VH_1x02_P3.96mm_Horizontal
J4: Power_Out; JST_VH_B2PS-VH_1x02_P3.96mm_Horizontal
J5: BT_LM62; PinHeader_1x03_P2.54mm_Vertical
J6: DSKY; PinHeader_1x05_P2.54mm_Vertical
J7: PWR_SW; PinHeader_1x02_P2.54mm_Vertical
J8: ICSP; PinHeader_1x05_P2.54mm_Vertical
J9: Heater; PinHeader_1x02_P2.54mm_Vertical
J10: USB_C_Receptacle_4085; USB_C_Receptacle_GCT_USB4085
L1: 10uH; L_12x12mm_H4.5mm
Q1, Q3: SSM3K341R; SOT-23
Q2, Q8, Q10: DMN65D8L; SOT-23
Q4, Q6, Q9, Q11: FDN340P; SOT-23
R1, R2, R3, R4, R30: 150; R_0805_2012Metric_Pad1.20x1.40mm_HandSolder
R5, R6, R18, R31: 5K1; R_0603_1608Metric
R7: 10mR; R_1206_3216Metric
R8: 10K_NTC; R_0603_1608Metric
R9, R22, R23, R24, R25, R26, R27, R28, R29: 10K; R_0603_1608Metric
R10, R11, R14, R32, R33: 12; R_0603_1608Metric
R12, R13, R15, R16, R17, R19, R20: 27R; R_0603_1608Metric
R21: 91K; R_0603_1608Metric
RN1, RN2, RN3, RN4, RN5, RN6, RN8, RN9, RN10: 1K; R_Array_Convex_4x0612
RN7, RN11: 10K; R_Array_Convex_4x0612
SW1: PTS526; SW_SPST_SKQG_WithStem
U1, U7: ACS711xLCTR-25AB; SOIC-8_3.9x4.9mm_P1.27mm
U2: AP33772; WQFN-24-1EP_4x4mm_P0.5mm_EP2.6x2.6mm
U3, U8: IS281-4; SOIC-16_4.55x10.3mm_P1.27mm
U4: Q294700DSGR; WDFN-8-1EP_2x2mm_P0.5mm_EP0.8x1.2mm
U5: SCF4030-12-0X
U6: AONR21321; DFN-8-1EP_3x3mm_P0.65mm_EP1.7x2.05mm
U9: IRS2184; SOIC-8-1EP_3.9x4.9mm_P1.27mm_EP2.514x3.2mm_ThermalVias
U10: BA033CC0FP-E2; TO-252-2
U11, U12, U16: AON7522E; DFN-8-1EP_3x3mm_P0.65mm_EP1.7x2.05mm
U13: LM62CIM3/NOPB; SOT-23
U14, U15: FAN3100TSX; SOT-23-5
U17: dsPIC30F3011-PT; QFN-44-1EP_8x8mm_P0.65mm_EP6.45x6.45mm
U18: FT230XQ; QFN-16-1EP_4x4mm_P0.65mm_EP2.1x2.1mm

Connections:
+5C: C5.1, C12.1, C22.1, C25.1, C26.1, C33.1, C36.1, C37.1, C39.1, C40.2, D12.1 (K), J5.1, J8.2, Q9.2 (S), R18.1, R23.1, R25.2, R26.2, R31.1, RN3.6 (R3.2), RN4.5 (R4.2), RN9.1 (R1.1), RN9.2 (R2.1), RN9.3 (R3.1), RN9.4 (R4.1), RN10.1 (R1.1), RN11.6 (R3.2), U1.8 (VCC), U7.8 (VCC), U10.3 (VO), U13.1 (G), U17.7 (VDD0), U17.17 (AVDD), U17.28 (VDD1), U17.40 (VDD2), U18.1 (VCCIO), U18.8 (3V3OUT), U18.9 (~RESET), U18.10 (VCC)
/BCsense: C38.1, RN4.6 (R3.2), U17.20 (EMUC3/AN1/VREF-/CN3/RB1)
/BTStrapSig: C23.2, L1.1, U9.6 (VS), U11.1 (S), U11.2 (S), U11.3 (S), U12.5 (D), U12.6 (D), U12.7 (D), U12.8 (D), U12.9 (D)
/BV_Fault: D6.2 (A), RN3.3 (R3.1), U17.36 (~FLTA/INT0/RE8)
/BattIn: F3.2, RN3.8 (R1.2), U1.3 (IP-), U1.4 (IP-)
/Btemp: C27.1, RN10.6 (R3.2), U17.21 (AN2/~SS1/CN4/RB2)
/Btemp_in: J5.3, RN10.3 (R3.1)
/CC1: J10.A5 (CC1), R5.2, U2.17 (CC1)
/CC2: J10.B5 (CC2), R6.2, U2.16 (CC2)
/CCsense: C34.1, RN10.7 (R2.2), U17.27 (AN8/RB8)
/CCsense_in: RN10.2 (R2.1), U7.7 (VIOUT)
/CH_Boost+: U14.3 (IN+), U17.8 (PWM3H/RE5)
/CHctrl+: U9.1 (IN), U17.10 (PWM2H/RE3)
/C_Fault: D13.1 (K), D28.1 (K), Q9.1 (G), RN4.4 (R4.1), U1.6 (~FAULT), U7.6 (~FAULT), U9.2 (~SD)
/C_Fault_In: Q9.3 (D), R27.2, U17.42 (EMUC2/OC1/IC1/INT1/RD0)
/ChargeVoltage: C30.1, D12.2 (A), R24.1, RN3.5 (R4.2), U17.19 (EMUD3/AN0/VREF+/CN2/RB0)
/ExtBus: C43.1, C44.1, C45.1, F5.1, FB4.2, Q11.2 (S), R9.1, R29.1, U5.3 (T2), U6.1 (S), U6.2 (S), U6.3 (S)
/Heat_CTRL: U15.3 (IN+), U17.14 (PWM1H/RE1)
/HighCHfet: R10.2, U11.4 (G)
/IntBus: Q4.3 (D), Q6.3 (D), RN11.8 (R1.2), U1.1 (IP+), U1.2 (IP+), U5.1 (T1)
/IntSwitched: C18.1, D16.2 (A), D17.2 (A), Q4.2 (S), Q6.2 (S), U9.5 (VCC), U14.1 (VDD), U15.1 (VDD)
/KeepAlive: Q8.1 (G), RN11.5 (R4.2), U17.5 (RF0)
/LBatt_Cell_1: D4.2 (A), J1.2, R4.1, RN1.8 (R1.2), RN2.2 (R2.1), U3.13 (out2_E), U8.16 (out1_C)
/LBatt_Cell_2: D3.2 (A), J1.3, R3.1, RN1.7 (R2.2), RN2.3 (R3.1), U3.11 (out3_E), U8.14 (out2_C)
/LBatt_Cell_3: D2.2 (A), J1.4, R2.1, RN1.6 (R3.2), RN2.4 (R4.1), U3.9 (out4_E), U8.12 (out3_C)
/LBatt_Cell_4: D1.2 (A), J1.5, R1.1, RN1.5 (R4.2), U8.10 (out4_C)
/LithCell_V1: C15.1, RN7.8 (R1.2), RN8.1 (R1.1), U17.23 (AN4/QEA/IC7/CN6/RB4)
/LithCell_V2: C17.1, RN7.7 (R2.2), RN8.2 (R2.1), U17.24 (AN5/QEB/IC8/CN7/RB5)
/LithCell_V3: C19.1, RN7.6 (R3.2), RN8.3 (R3.1), U17.25 (AN6/OCFA/RB6)
/LithCell_V4: C21.1, RN7.5 (R4.2), RN8.4 (R4.1), U17.26 (AN7/RB7)
/LowCHfet: R11.2, U12.4 (G)
/MCLR: C31.1, D21.1 (K), J8.1, U17.18 (~MCLR)
/Mult_B1: RN5.1 (R1.1), U17.15 (PWM1L/RE0)
/Mult_B2: RN5.2 (R2.1), U17.37 (EMUD2/OC2/IC2/INT2/RD1)
/Mult_B3: RN5.3 (R3.1), U17.41 (OC3/RD2)
/Mult_B4: RN5.4 (R4.1), U17.38 (OC4/RD3)
/Mult_SEL: D7.2 (A), D8.2 (A), D9.2 (A), D10.2 (A), U3.2 (in1_C), U3.4 (in2_C), U3.6 (in3_C), U3.8 (in4_C), U17.11 (PWM2L/RE2)
/PGMC: J8.5, R31.2, R32.1, U17.1 (PGC/EMUC/U1RX/SDI1/SDA/RF2)
/PGMD: J8.4, R18.2, R33.1, U17.44 (PGD/EMUD/U1TX/SDO1/SCL/RF3)
/PO_EN: D28.2 (A), Q2.1 (G), RN4.1 (R1.1)
/Pctrl_IN: Q8.3 (D), RN4.2 (R2.1)
/Pctrl_OUT: C41.1, D24.2 (A), Q4.1 (G), Q6.1 (G), RN4.7 (R2.2), RN11.1 (R1.1)
/PowerOutEnable: RN4.8 (R1.2), U17.31 (OSC2/CLKO/RC15)
/PowerOutput: D20.2 (A), D27.2 (A), J4.1, R30.2, U6.5 (D), U6.6 (D), U6.7 (D), U6.8 (D), U6.9 (D)
/Pre_Charge: R28.1, U17.43 (SCK1/RF6)
/U1RX: R19.2, R26.1, U17.35 (EMUC1/SOSCO/T1CK/U1ARX/CN0/RC14)
/U1TX: R20.2, U17.32 (EMUD1/SOSCI/T2CK/U1ATX/CN1/RC13)
/U2RX: R12.2, R25.1, U17.3 (U2RX/CN17/RF4)
/U2TX: R13.2, U17.2 (U2TX/CN18/RF5)
/USB_D+: J10.A6 (D+), J10.B6 (D+), R17.1
/USB_D-: J10.A7 (D-), J10.B7 (D-), R16.1
/V_Bus_Stat: D5.2 (A), R21.2, R23.2, U17.9 (PWM3L/RE4)
/__PwrKey: D25.2 (A), RN11.3 (R3.1), U17.4 (RF1)
GND: C4.2, C5.2, C6.2, C7.2, C8.2, C9.2, C10.2, C11.2, C12.2, C13.2, C14.2, C15.2, C16.2, C17.2, C18.2, C19.2, C20.2, C21.2, C22.2, C24.2, C25.2, C26.2, C27.2, C28.2, C29.2, C30.2, C31.2, C32.2, C33.2, C34.2, C35.2, C36.2, C37.2, C38.2, C39.2, C40.1, C41.2, C42.2, C44.2, C45.2, D11.1 (K), J1.1, J2.2, J3.2, J4.2, J5.2, J6.2, J6.4, J7.2, J8.3, J10.A1 (GND), J10.A12 (GND), J10.B1 (GND), J10.B12 (GND), J10.S1 (SHIELD), Q1.2 (S), Q2.2 (S), Q3.2 (S), Q8.2 (S), Q10.2 (S), R5.1, R6.1, R8.1, R21.1, R27.1, RN2.1 (R1.1), RN3.4 (R4.1), RN6.5 (R4.2), RN6.6 (R3.2), RN6.7 (R2.2), RN6.8 (R1.2), RN8.5 (R4.2), RN8.6 (R3.2), RN8.7 (R2.2), RN8.8 (R1.2), RN11.4 (R4.1), SW1.1 (A), U1.5 (GND), U2.3 (GND), U2.25 (PAD), U3.15 (out1_E), U4.6 (VSS), U4.9 (PAD), U7.5 (GND), U8.2 (in1_C), U8.4 (in2_C), U8.6 (in3_C), U8.8 (in4_C), U9.3 (COM), U9.9 (PAD), U10.2 (GND), U12.1 (S), U12.2 (S), U12.3 (S), U13.3 (S), U14.2 (GND), U14.4 (XREF), U15.2 (GND), U15.4 (XREF), U16.1 (S), U16.2 (S), U16.3 (S), U17.6 (VSS0), U17.16 (AVSS), U17.29 (VSS1), U17.39 (VSS2), U17.45 (PAD), U18.3 (GND), U18.4 (~CTS), U18.13 (GND), U18.17 (GND)
unnamed: C1.1, C3.2, RN1.2 (R2.1), U4.4 (V2)
unnamed: C1.2, C2.1, RN1.3 (R3.1), U4.3 (V3)
unnamed: C2.2, RN1.4 (R4.1), U4.2 (V4)
unnamed: C6.1, RN3.1 (R1.1), U4.1 (VDD)
unnamed: C7.1, U2.20 (V5V)
unnamed: C8.1, U2.15 (IFB)
unnamed: C9.1, U4.7 (CD)
unnamed: C3.1, C10.1, RN1.1 (R1.1), U4.5 (V1)
unnamed: C11.1, FB1.2, U7.1 (IP+), U7.2 (IP+)
unnamed: C13.1, C14.1, FB2.2, U10.1 (VI)
unnamed: C16.1, C20.1, C24.1, U7.3 (IP-), U7.4 (IP-), U11.5 (D), U11.6 (D), U11.7 (D), U11.8 (D), U11.9 (D)
unnamed: C23.1, D17.1 (K), U9.8 (VB)
unnamed: C28.1, F4.2, J6.5
unnamed: C29.1, RN10.5 (R4.2), U17.22 (AN3/INDX/CN5/RB3)
unnamed: C32.1, C35.1, D22.3 (K), FB4.1
unnamed: C42.1, D23.2 (A), D24.1 (K), D25.1 (K)
unnamed: C43.2, FB3.1, Q3.3 (D)
unnamed: D1.1 (K), RN2.5 (R4.2)
unnamed: D2.1 (K), RN2.6 (R3.2)
unnamed: D3.1 (K), RN2.7 (R2.2)
unnamed: D4.1 (K), RN2.8 (R1.2)
unnamed: D5.1 (K), U2.23 (PWR_EN)
unnamed: D6.1 (K), Q1.1 (G), U4.8 (OUT)
unnamed: D7.1 (K), RN5.5 (R4.2), U3.7 (in4_A)
unnamed: D8.1 (K), RN5.6 (R3.2), U3.5 (in3_A)
unnamed: D9.1 (K), RN5.7 (R2.2), U3.3 (in2_A)
unnamed: D10.1 (K), RN5.8 (R1.2), U3.1 (in1_A)
unnamed: D11.2 (A), R22.1
unnamed: D13.2 (A), Q10.1 (G), R28.2
unnamed: D15.1 (K), D16.1 (K), D27.1 (K), FB2.1
unnamed: D19.1 (K), D20.1 (K), F4.1
unnamed: D21.2 (A), RN10.8 (R1.2)
unnamed: D22.1 (A), D22.2 (A), L1.2, U16.5 (D), U16.6 (D), U16.7 (D), U16.8 (D), U16.9 (D)
unnamed: D23.1 (K), J7.1, SW1.2 (B)
unnamed: F1.1, J2.1
unnamed: F2.1, J10.A4 (VBUS), J10.A9 (VBUS), J10.B4 (VBUS), J10.B9 (VBUS)
unnamed: F2.2, R7.2, U2.1 (ISENP)
unnamed: F3.1, J3.1
unnamed: F5.2, J9.1
unnamed: FB3.2, J9.2
unnamed: J6.1, R12.1
unnamed: J6.3, R13.1
unnamed: Q1.3 (D), U5.2 (Trig)
unnamed: Q2.3 (D), R9.2, U6.4 (G)
unnamed: Q3.1 (G), R15.2
unnamed: Q10.3 (D), Q11.1 (G), R29.2
unnamed: Q11.3 (D), R30.1
unnamed: R1.2, U3.10 (out4_C)
unnamed: R2.2, U3.12 (out3_C)
unnamed: R3.2, U3.14 (out2_C)
unnamed: R4.2, U3.16 (out1_C)
unnamed: R8.2, U2.13 (OTP)
unnamed: R10.1, U9.7 (HO)
unnamed: R11.1, U9.4 (LO)
unnamed: R14.1, U16.4 (G)
unnamed: R14.2, U14.5 (OUT)
unnamed: R15.1, U15.5 (OUT)
unnamed: R16.2, U18.7 (USBDM)
unnamed: R17.2, U18.6 (USBDP)
unnamed: R19.1, U18.15 (TXD)
unnamed: R20.1, U18.2 (RXD)
unnamed: R22.2, U2.6 (GPIO4)
unnamed: RN4.3 (R3.1), U1.7 (VIOUT)
unnamed: RN7.1 (R1.1), U8.15 (out1_E)
unnamed: RN7.2 (R2.1), U8.13 (out2_E)
unnamed: RN7.3 (R3.1), U8.11 (out3_E)
unnamed: RN7.4 (R4.1), U8.9 (out4_E)
unnamed: RN9.5 (R4.2), U8.7 (in4_A)
unnamed: RN9.6 (R3.2), U8.5 (in3_A)
unnamed: RN9.7 (R2.2), U8.3 (in2_A)
unnamed: RN9.8 (R1.2), U8.1 (in1_A)
unnamed: RN10.4 (R4.1), U13.2 (D)
unnamed: R32.2, U2.4 (SDA)
unnamed: R33.2, U2.5 (SCL)
unnamed: RN6.4 (R4.1), U2.7 (GPIO2)
unnamed: RN6.3 (R3.1), U2.8 (GPIO1)
unnamed: RN6.2 (R2.1), U2.9 (GPIO3)
unnamed: RN6.1 (R1.1), U2.11 (GPIO5)
unnamed: C4.1, U2.12 (V3VD)
VBUS: D15.2 (A), D19.2 (A), F1.2, FB1.1, R7.1, R24.2, U2.24 (VCC)

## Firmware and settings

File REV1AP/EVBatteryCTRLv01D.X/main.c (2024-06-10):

/*Copyright (c) <2024> <Jarrett Cigainero>

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
THE SOFTWARE IS PROVIDED "AS IS", WITHOUT WARRANTY OF ANY KIND, EXPRESS OR
IMPLIED, INCLUDING BUT NOT LIMITED TO THE WARRANTIES OF MERCHANTABILITY,
FITNESS FOR A PARTICULAR PURPOSE AND NONINFRINGEMENT. IN NO EVENT SHALL THE
AUTHORS OR COPYRIGHT HOLDERS BE LIABLE FOR ANY CLAIM, DAMAGES OR OTHER
LIABILITY, WHETHER IN AN ACTION OF CONTRACT, TORT OR OTHERWISE, ARISING FROM,
OUT OF OR IN CONNECTION WITH THE SOFTWARE OR THE USE OR OTHER DEALINGS IN THE
SOFTWARE. */

#include "common.h"

/* Include the Source AND Headers HERE or else mplab slowINHIBIT_Timergets pissy for some reason.
 * Don't bother trying to include the source and header files into the project,
 * it doesn't work. Either I'm doing it wrong or it's broken, but what I have here WORKS SO DON'T TOUCH IT.
 */
//#include <p30f3011.h>
//#include <libpic30.h>
//#include <xc.h>
#include "defines.h"
#include "chipconfig.h"
#include "IRQs.h"
#include "sysIRQs.c"
#include "dataIRQs.c"
#include "trapIRQs.c"
#include "common.h"
#include "SysCalculations.c"
#include "SysCalculations.h"
#include "DataIO.h"
#include "DataIO.c"
#include "Init.h"
#include "Init.c"
#include "display.c"
#include "display.h"
#include "eeprom.c"
#include "eeprom.h"
#include "checksum.c"
#include "checksum.h"
#include "sysChecks.c"
#include "sysChecks.h"
#include "safetyChecks.c"
#include "safetyChecks.h"
#include "regulate.c"
#include "regulate.h"
#include "poweroptions.c"
#include "poweroptions.h"

/* Program Start */
/***********************************************************
***********************************************************/
int main(void){
    /* General 2 IO This IO needs to be configured first so that keepalive signal can be enabled as soon as possible. */
    GENERAL2_TRIS = GENERAL2_DIR;
    GENERAL2_LAT = 0;
    GENERAL2_PORT = 0;
    //Enable Keep Alive signal. System keeps itself on while main_power is enabled.
    for(unsigned int i=0;i<65534;i++){KeepAlive = 1;} //Do nothing loop. Waste some time.
    /* Analog inputs */
    //Initialize PORTB first.
    ANALOG_TRIS = ANALOG_DIR;          //set portb to analog inputs.
    ANALOG_LAT = 0;
    ANALOG_PORT = 0; //clear portb
    configure_IO();
    //Calculate space required for eeprom storage.
    cfg_space = sizeof(sets) / 2;
    vr_space = sizeof(vars) / 2;
    dsky_space = sizeof(dsky) / 2;
    Exception_Check();
    //Get either default or custom settings.
    get_settings();
    //Get variable data if it exists.
    get_variables();
    //Do an initial reset and warm start check.
    first_check();
    //Initialize Systems.
    Run_Level = Cal_Mode;
    for(int i=0;i<sets.Cell_Count;i++){
        temp_Cell_Voltage_Average[i] = 0;
    }
    Init();
    Deep_Sleep_timer_reset();   //Located in dataIRQs.c
    PowerOffTimer = sets.PowerOffAfter-1;
    //send_string("Init. \n\r", PORT1);
    send_string(I_Auto, "Init. \n\r", PORT2);

/*****************************/
    // Main Loop.
/*****************************/
    /* Everything is run using IRQs from here on out.
     * Look in the other source files that MPLAB doesn't open automatically.
     */
    for (;;)        //loop forever. or not, idc, we have IRQs for stuff.
    {
        //Check trap flag bits.
        Exception_Check();
        if(Run_Level == Crit_Err)death_loop();
        //Deep sleep check.
        if(STINGbits.deep_sleep){
            Batt_IO_OFF();               //Turn off all IO before sleeping.
            //CPUact = 0;      //Turn CPU ACT light off.
            Deep_Sleep();        //Cuts main power to self.
            /* If the keep alive pin isn't used or if the power control hardware
             * is faulty then this does nothing and the micro will
             * sleep on the next instruction. Even in Sleep it still draws
             * nearly a quarter of a watt! WTF Microchip? Why did I choose
             * this microcontroller again?
             * It's what I had on hand when I first started developing this.
             * Oh well, we have ways of getting around it so it works for now.
             */
            Sleep();
            STINGbits.deep_sleep = 0;
        }
        else {
            Idle();                 //Idle Loop, saves power.
        }
    }
    return 0;
}

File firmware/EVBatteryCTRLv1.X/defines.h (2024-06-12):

/*Copyright (c) <2024> <Jarrett Cigainero>

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
THE SOFTWARE IS PROVIDED "AS IS", WITHO70054eUT WARRANTY OF ANY KIND, EXPRESS OR
IMPLIED, INCLUDING BUT NOT LIMITED TO THE WARRANTIES OF MERCHANTABILITY,
FITNESS FOR A PARTICULAR PURPOSE AND NONINFRINGEMENT. IN NO EVENT SHALL THE
AUTHORS OR COPYRIGHT HOLDERS BE LIABLE FOR ANY CLAIM, DAMAGES OR OTHER
LIABILITY, WHETHER IN AN ACTION OF CONTRACT, TORT OR OTHERWISE, ARISING FROM,
OUT OF OR IN CONNECTION WITH THE SOFTWARE OR THE USE OR OTHER DEALINGS IN THE
SOFTWARE. */

#ifndef DEFINES_H
#define	DEFINES_H
//##############################################################################
// Tm = 32767 * (1 / (((clkSpeedmhz * PLL) / 4) / tiksPerIRQ))
//#define IPS 29.48;   //million instructions per second.
#define IPS 14.74   //million instructions per second.
//Analog
#define sample_Average 2
//PWM period
#define PWM_Period 100
#define PWM_MaxHeat (PWM_Period*2)*0.9
#define PWM_MaxChrg (PWM_Period*2)*0.98
#define PWM_MaxBoost_LO 0.52
#define PWM_MaxBoost_HI 0.72
#define PWM_MaxBoost_LN (PWM_Period*2)*PWM_MaxBoost_LO
#define PWM_MaxBoost_HN (PWM_Period*2)*PWM_MaxBoost_HI
//Charger
#define charge_Max_Level 0.65
#define C_Min_Voltage 3.0
#define Eval_Start 50
//#define IPS 7.37   //million instructions per second.
#define BAUD1 9600  //Default BAUD rate for PORT 1
#define BAUD2 9600  //Default BAUD rate for PORT 2
#define calc_125 0.00003472 //Value for calculating the total current in and out of battery every second.
//Firmware Version String
#define version "\n\rFirmware: V0.1-Dev\n\r2S-4S Compatible Cell Configs.\n\r(C) Haptic Solutions Inc. (2024)\n\r"
//IO inputs
#define PWR_SW !PORTFbits.RF1 //Power on/off switch, button, or key. Active low input.
#define BV_Fault PORTEbits.RE8  //Battery Voltage Fault.
#define C_Fault PORTDbits.RD0 //Battery or charge input/output current fault.
//Analog inputs
#define ChargeVoltage ADCBUF0 //Voltage
#define BCsense ADCBUF1 //Current
#define Btemp ADCBUF2 //Batt Temp
#define Mtemp ADCBUF3 //My Temp
#define LithCell_V1 ADCBUF4 //Cell 1 Volts
#define LithCell_V2 ADCBUF5 //Cell 2 Volts
#define LithCell_V3 ADCBUF6 //Cell 3 Volts
#define LithCell_V4 ADCBUF7 //Cell 4 Volts
#define CCsense ADCBUF8 //CCsense
//IO outputs
#define KeepAlive LATFbits.LATF0 //Enables power to self and system.
#define Cell_Volt LATEbits.LATE4 //Cell voltage sense enable.
#define PowerOutPreCharge LATFbits.LATF6 //Power output pre-charge control
#define PowerOutEnable LATCbits.LATC15 //Power output enable.
//LED outputs
#define Mult_SEL LATEbits.LATE2 //LED and Cell ballance multiplexed select.
#define Mult_B1 LATEbits.LATE0
#define Mult_B3 LATDbits.LATD2
#define Mult_B2 LATDbits.LATD1
#define Mult_B4 LATDbits.LATD3
#define LED_dir_1 TRISE
#define LED_dir_2 TRISD
#define LED_HiZ_1 PWM_TRIS_DIR | 0x0001
#define LED_HiZ_2 GENERAL3_DIR | 0x000E
#define DFLT_1 PWM_TRIS_DIR
#define DFLT_2 GENERAL3_DIR

#define Heat_CTRL PDC1  //Heater PWM.
#define CHctrl PDC2     //Charge buck PWM.
#define CH_Boost PDC3   //Charge boost PWM.

//IO
#define ANALOG_DIR 0x01FF
#define ANALOG_TRIS TRISB
#define ANALOG_LAT LATB
#define ANALOG_PORT PORTB

#define GENERAL1_DIR 0x1FFF
#define GENERAL1_TRIS TRISC
#define GENERAL1_LAT LATC
#define GENERAL1_PORT PORTC

#define GENERAL2_DIR 0xFFBE
#define GENERAL2_TRIS TRISF
#define GENERAL2_LAT LATF
#define GENERAL2_PORT PORTF

#define GENERAL3_DIR 0xFFF1
#define GENERAL3_TRIS TRISD
#define GENERAL3_LAT LATD
#define GENERAL3_PORT PORTD

#define PWM_TRIS_DIR 0xFFEA
#define PWM_TRIS TRISE
#define PWM_LAT LATE
#define PWM_PORT PORTE

//Memory Defines
/* This assumes the compiler puts the stack at the end of memory space just after
 * the user variables and the stack pointer counts up */
#define ramSize 0x07F0 //Size of memory.
#define ramAddressStart 0x0800  //Where the dsPIC30F4011's ram address starts.
#define stackFaultMax ramSize + ramAddressStart - 1
#define ramFree (ramSize + ramAddressStart) - 2 //Minus 15 bytes of ram. If the stack intrudes on this then it should throw an error code before a complete system crash and undefined behavior.

//General
#define yes 1
#define no 0
#define none 0
#define Ltest 4
#define Debug 3
#define Ballance 2
#define on 1
#define off 0
#define set 1
#define clear 0
#define NULL 0
#define input 1
#define output 0
#define maxFCodes 20
#define I_Auto -1

//Constants
#define Max_Cell_Count 4
#define SOC_Cycles 8
#define AuxFuse 5       //Aux charge port fuse rating placeholder.
#define PreChargeTime 2 //Output pre-charge timer placeholder.
#define LED_Brightness 10
#define V_REF 3.35      //Measured reference voltage placeholder

//Run Levels
#define Shutdown 0
#define Crit_Err 1
#define Heartbeat 2
#define Cal_Mode 3
#define On_W_Err 4
#define All_Sys_Go 5

//Charge Session Levels
#define UnknownStart 0
#define EmptyStart 1
#define FullStart 2

//Heater calibration states.
#define notrun 0
#define initialize 1
#define calibrating 2
#define ready 3
#define error 4
#define disabled 5
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

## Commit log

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2024-02-12 Changed secondary protection to use triggable fuse. Restructured repo.
    [BTMS.kicad_pcb, BTMS.kicad_sch, BTMS.sch]
2024-02-12 Updated schematic and readme files.
    [BTMS.kicad_sch]
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2024-02-13 Cleaned up some things in schematic. Switched to a larger grid size. Using different USB-C power trigger chip.
    [BTMS.kicad_pcb, BTMS.kicad_sch]
2024-02-14 Added connectors to schematic. Updated firmware to accomodate new featers, and omit unneeded features.
    [BTMS.kicad_sch]
2024-02-14 Updated some capacitors for correct voltage values.
    [BTMS.kicad_sch]
2024-02-14 Started working on PCB layout.
    [BTMS.kicad_pcb, BTMS.kicad_sch]
2024-02-14 Fixed 3.3v regulator not having correct pinout. Progressed board layout.
    [BTMS.kicad_pcb]
2024-02-15 Shrunk silkscreen text to compact parts more.
    [BTMS.kicad_pcb]
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2024-02-17 Board routing complete and cleaned up all board DRV violations except some silkscreen warning on the bottom edge.
    [BTMS.kicad_pcb, BTMS.kicad_sch]
2024-02-17 Added backside ground planes.
    [BTMS.kicad_pcb]
2024-02-17 Cleaned up ground plane islands.
    [BTMS.kicad_pcb]
2024-02-17 Extended board and placed mounting points.
    [BTMS.kicad_pcb, BTMS.kicad_sch]
2024-02-17 Cleaned up connector silkscreens. No more DRC warnings.
    [BTMS.kicad_pcb, BTMS.kicad_sch]
2024-02-17 Added groundplanes to front and middle layer. Cleaned up islands and tails.
    [BTMS.kicad_pcb]
2024-02-17 Added solder mask and solder paste lines for high-current traces.
    [BTMS.kicad_pcb]
2024-02-18 Cleaned up some things.
    [BTMS.kicad_pcb]
2024-02-18 Extended front groundplane and cleaned up islands and tails.
    [BTMS.kicad_pcb]
2024-02-18 Added power switch button. Added credits and description silkscreening.
    [BTMS.kicad_pcb, BTMS.kicad_sch]
2024-02-18 Added g-code files for board.
    [BTMS-B_Cu.gbr, BTMS-B_Mask.gbr, BTMS-B_Paste.gbr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]
2024-02-19 Added parts list order.
    [BTMS.csv, BTMS.kicad_sch, BTMS.ods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]
2024-02-19 Fixed mirrored silkscreen on back layer.
    [BTMS-B_Cu.gbr, BTMS-B_Mask.gbr, BTMS-B_Paste.gbr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]
2024-02-19 Cleaned up more tails and islands.
    [BTMS-B_Cu.gbr, BTMS-B_Mask.gbr, BTMS-B_Paste.gbr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]
2024-02-19 Cleaned up more tails and islands on PCB.
    [BTMS-B_Cu.gbr, BTMS-B_Mask.gbr, BTMS-B_Paste.gbr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]
2024-02-19 Added 10K pullup resistors to dsPIC's serial RX lines.
    [BTMS-B_Cu.gbr, BTMS-B_Mask.gbr, BTMS-B_Paste.gbr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]
2024-02-19 Added ground connection to CTS pin on FTDI chip.
    [BTMS-B_Cu.gbr, BTMS-B_Mask.gbr, BTMS-B_Paste.gbr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]
2024-02-19 Cleaned up some things. Price optimized capacitors.
    [BTMS-B_Cu.gbr, BTMS-B_Mask.gbr, BTMS-B_Paste.gbr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]
2024-02-19 Widened a trace for charge input.
    [BTMS-B_Cu.gbr, BTMS-B_Mask.gbr, BTMS-B_Paste.gbr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]
2024-02-19 Removed unneeded 15V zener diodes. Added pre-charge circuit to output to reduce inrush current. Removed power control circuit from FTDI chip. Fixed USB-C connector.
    [BTMS-B_Cu.gbr, BTMS-B_Mask.gbr, BTMS-B_Paste.gbr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]
2024-02-19 Cleaned up some things. Added silkscreen artwork to back.
    [BTMS-B_Cu.gbr, BTMS-B_Mask.gbr, BTMS-B_Paste.gbr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]
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2024-02-28 Fixed bugs caused by enabling compiler optimizations such as the address error fault when trying to access NVM or PGM memories.
    [DataIO.c, DataIO.h, Init.c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]
2024-03-04 Fixed chip resistor array footprints. <- Need to finish re-routing traces and update G-Code files.
    [BTMS.kicad_pcb, BTMS.kicad_sch]
2024-03-05 Finished routing for fixed resistor array footprints. Added I2C lines to USB-3 PD chip to dsPIC. Cleaned up ground-plane islands and tails.
    [BTMS-B_Cu.gbr, BTMS-B_Mask.gbr, BTMS-B_Paste.gbr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]
2024-03-06 Updated revision and date code.
    [BTMS-B_Cu.gbr, BTMS-B_Mask.gbr, BTMS-B_Paste.gbr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]
2024-03-09 Got firmware somewhat functional and kinda stable. Still crashes sometimes but fails gracefully enough to not damage anything. Need to finish updating schematic and board layout.
    [DataIO.c, DataIO.h, Init.c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]
2024-03-10 Fixed a few bugs with initialization of first run variables. Added charging system recycle error code and stop/reset function.
    [Init.c, common.h, defines.h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]
2024-03-11 Added LED test and fixed cell ballance driver output.
    [common.h, defines.h, sysIRQs.c]
2024-03-14 Began expirimenting with clock switching to reduce power draw. Managed to double idle runtime. Started runtime calculations. Fixed some things in schematic.
    [BTMS.kicad_sch]
2024-03-21 Rerouted board after making changes to schematic.
    [ASPI-4030S-4R7M-T.step, BTMS.kicad_pcb, BTMS.kicad_sch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]
2024-03-21 Fixed power button not having a signal to dsPIC.
    [BTMS.kicad_pcb, BTMS.kicad_sch]
2024-03-21 Cleaned up ground-plane tails and islands. Added high-current paths using solder mask zones. Updated hardware todo list.
    [BTMS-B_Cu.gbr, BTMS-B_Mask.gbr, BTMS-B_Paste.gbr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]
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2024-03-21 Added four 10uF capacitors to ExtBus. Rerouted some things.
    [BTMS-B_Cu.gbr, BTMS-B_Mask.gbr, BTMS-B_Paste.gbr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]
2024-03-22 Fixed P-Channel mosfets on ballance circuit and cell voltage front-end being connected backwards in schematic.
    [BTMS-B_Cu.gbr, BTMS-B_Mask.gbr, BTMS-B_Paste.gbr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]
2024-03-26 Cleaned up some things and shifted some parts and traces around.
    [BTMS-B_Cu.gbr, BTMS-B_Mask.gbr, BTMS-B_Paste.gbr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]
2024-03-26 Cleaned up and added more high current paths.
    [BTMS-B_Cu.gbr, BTMS-B_Mask.gbr, BTMS-B_Paste.gbr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]
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2024-04-06 Cleaned up some things. Added capacitor after D1 Reviewed design for next revision prototype build.
    [BTMS-B_Cu.gbr, BTMS-B_Mask.gbr, BTMS-B_Paste.gbr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]
2024-04-30 Cleaned up some thing and adjust some resistor values in board design. Testing design is going well. Need to power current sense IC's directly or through mosfet. Need to add level shifter inline with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
    [BTMS.csv, BTMS.kicad_pcb, BTMS.kicad_sch]
2024-05-01 Changed firmware to use average cell voltage for HV detect rountine. Was too sensitive to noise before. Added attributes paramter to error code system. Made error codes a little more verbose. Changed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
    [BTMS.kicad_sch]
2024-05-06 Fixed problem where charge mosfet driver chip needs 5V logic levels to work. Replaced driver chip config pull-down resistor with solderable jumper pad. Removed 100 ohm resistor on dsPIC analog voltag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
    [BTMS-B_Cu.gbr, BTMS-B_Mask.gbr, BTMS-B_Paste.gbr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]
2024-05-06 Added pre-charge circuit for output. Added automatic Cell count function to firmware.
    [BTMS-B_Cu.gbr, BTMS-B_Mask.gbr, BTMS-B_Paste.gbr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]
2024-05-22 Added USB-PD support to firmware via I2C. Testing. Fixed bug where system would keep getting open circuit voltage when it's not supposed to causing battery % to jump around. Changed settings unlock c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
    [ASPI-4030S-4R7M-T.step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]
2024-05-22 Updated schematic and board to reflect changes made on prototype.
    [BTMS-B_Cu.gbr, BTMS-B_Mask.gbr, BTMS-B_Paste.gbr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]
2024-05-22 Cleaned up some things in schematic and board. Deleted files not needed that were added to repo by mistake. Added 30uF of capacitors to input side of buck-boost converter.
    [BTMS-B_Cu.gbr, BTMS-B_Mask.gbr, BTMS-B_Paste.gbr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]
2024-05-23 Updated REV1B(P)_schematic. Made copy of REV1A(P) schematic and board layout. Found a few diodes to be leaking current when in sleep mode. Need to fix.
    [BTMS.kicad_sch, REV1AP_BTMS.kicad_pcb, REV1P_BTMS.kicad_pcb]
2024-05-27 Cleaned up some files. Refactored parts of firmware. Improved speed of initial compensation stage. Changed open circuit voltage routine to only run on first startup. Added room for more types of volt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
    [BTMS.kicad_pcb, REV1P_BTMS.kicad_pcb]
2024-06-10 Revamped setting and information print page. Added settings editing command. Fixed bug where serial ports would sometimes skip data or text output. Added automatic battery evaluation system. Keep an 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
    [DataIO.c, DataIO.h, Init.c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]
2024-06-10 Fix bug where analog charger current input was using the same variable for 1s 8 sample averaging routine. Changed variable names to make less confusing. Added auto info readout on auto-evaluation eve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
    [DataIO.c, Init.c, SysCalculations.c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]
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2024-06-12 Added charge/discharge slowdown based on board temperature to existing battery charge/discharge temperature slowdown Fixed bug where blinkn' lights would sometimes blink erraticlly when a HUD was ena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
    [Init.c, dataIRQs.c, regulate.c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]
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2024-06-21 Added I2C ADC to REV.1B board. Added Battery Disconnect system to REV.1B board. Changed some dsPIC IO around to reflect changes. Changed power control system to not drain battery very quickly if swit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
    [BTMS.kicad_pcb, BTMS.kicad_sch]
2024-07-10 Updated board layout for REV. B Completed initial routing. Need to finish fixing circuit changes such as inrush current limiting. Need to refine board layout.
    [BTMS.kicad_pcb, BTMS.kicad_sch]
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2024-07-11 Finished implementing inrush current limiting changes. Need to verify design. Need to clean up tails and islands. Need to create BOM.
    [BTMS-B_Cu.gbr, BTMS-B_Mask.gbr, BTMS-B_Paste.gbr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]
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2024-07-19 Replaced USB-C input diode with P-Channel MOSFET array controlled by dsPIC and USB-PD chip. Added IO expanded chip for dsPIC and USB-C input control interface. Moved some things around on board layou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
    [BTMS.kicad_sch]
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2024-10-16 Updated project to KiCad > 8.0 Testing new design... Generated new BOM. Generated new schematic PDF. Generated new STEP file. Generated new GERBER files.
    [BTMS-B_Cu.gbr, BTMS-B_Mask.gbr, BTMS-B_Paste.gbr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]
